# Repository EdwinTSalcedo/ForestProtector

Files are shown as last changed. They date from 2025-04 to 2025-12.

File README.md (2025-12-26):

<h1 align="center">ForestProtector: An IoT Architecture Integrating Machine Vision and Deep Reinforcement Learning for Efficient Wildfire Monitoring</h1> 

This repository contains supplementary material for the paper [*"ForestProtector: An IoT Architecture Integrating Machine Vision and Deep Reinforcement Learning for Efficient Wildfire Monitoring"*](https://ieeexplore.ieee.org/document/10977677) (ICARA 2025). **Authors:** [Kenneth Bonilla-Ormachea](https://www.linkedin.com/in/kenneth-bonilla-ormachea-58b7a9240/), [Horacio Cuizaga](https://www.linkedin.com/in/horacuizr/), [Edwin Salcedo](https://www.linkedin.com/in/edwinsalcedo), [Sebastian Castro](https://www.linkedin.com/in/sebastian-castro-3969641a6), [Sergio Fernandez-Testa](https://www.linkedin.com/in/sergio5919/), and [Misael Mamani](https://www.linkedin.com/in/misaelmq680/).  

[[Project Page]](https://edwinsalcedo.com/publication/forest-protector) 
[[Preprint]](https://arxiv.org/abs/2501.09926)
[[Demo Video]](https://youtu.be/jGAHsTo3gg0)

<p align="center">
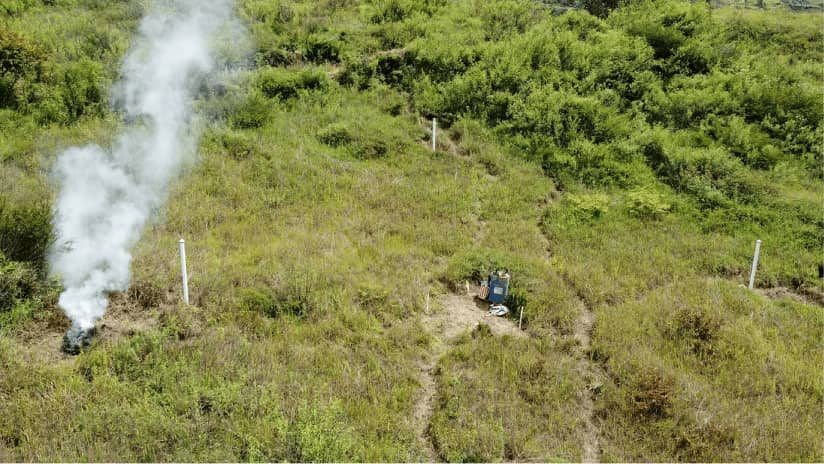
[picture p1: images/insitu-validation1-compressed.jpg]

</p>  

## TL;DR
- **Problem:** Early wildfire detection over large forest areas is critical in wildfire-prone regions. However, existing solutions are often expensive or prone to false positives.
- **Solution:** A low-cost wildfire detection system based on distributed IoT sensor nodes and a central edge gateway with computer vision monitoring a 360° field of view.
- **Key contribution:** A deep reinforcement learning agent dynamically controls the camera orientation based on real-time sensor data (smoke, temperature, humidity) and verifies smoke presence through a 3DCNN-based video recognizer, reducing false positives.

## Contents
[1. Overview](#overview) </br>
* [Motivation](#motivation) </br>
* [IoT architecture](#iotarchitecture) </br>
* [Hardware prototype](#hardwareprototype) </br>

[2. Deep reinforcement learning agent](#drlagent) </br>

[3. Computer vision system](#cvsystem) </br>
* [Datasets](#datasets) </br>
* [Detection metrics](#metrics) </br>
* [Demo](#demo) </br>

[4. Graphical user interface (GUI)](#gui) </br>

[5. Validation](#validation) </br>

[6. Project structure](#projectstructure) </br>

[7. Citation](#citation) </br>
<br>

## 1. Overview

### Motivation

Early detection of forest fires is crucial to minimizing environmental and socioeconomic damage, as longer-burning fires are significantly harder and costlier to extinguish. However, current detection systems using technologies like remote sensing, PTZ cameras, and UAVs are often expensive and require human involvement, limiting their practicality for continuous large-scale monitoring. To address this, we propose a system that uses a low-cost central gateway with computer vision to monitor a 360° field of view for smoke at long distances. A deep reinforcement learning agent enhances surveillance by dynamically adjusting the camera's orientation based on real-time data from distributed IoT sensors measuring smoke, temperature, and humidity.

### IoT architecture
The proposed system architecture consists of two main components: IoT sensor nodes and a central gateway. The sensor nodes, deployed near forests, monitor environmental conditions using various sensors, including those for temperature, humidity, barometric pressure, smoke, and water. The central gateway, based on an NVIDIA Jetson Nano board, collects data from these nodes via the LoRa protocol. The gateway then utilizes a deep reinforcement learning agent to control the gateway camera's perspective, focusing on potential nearby campfires, and employs a computer vision algorithm to verify the presence of smoke in the high-risk region.

<p align="center">
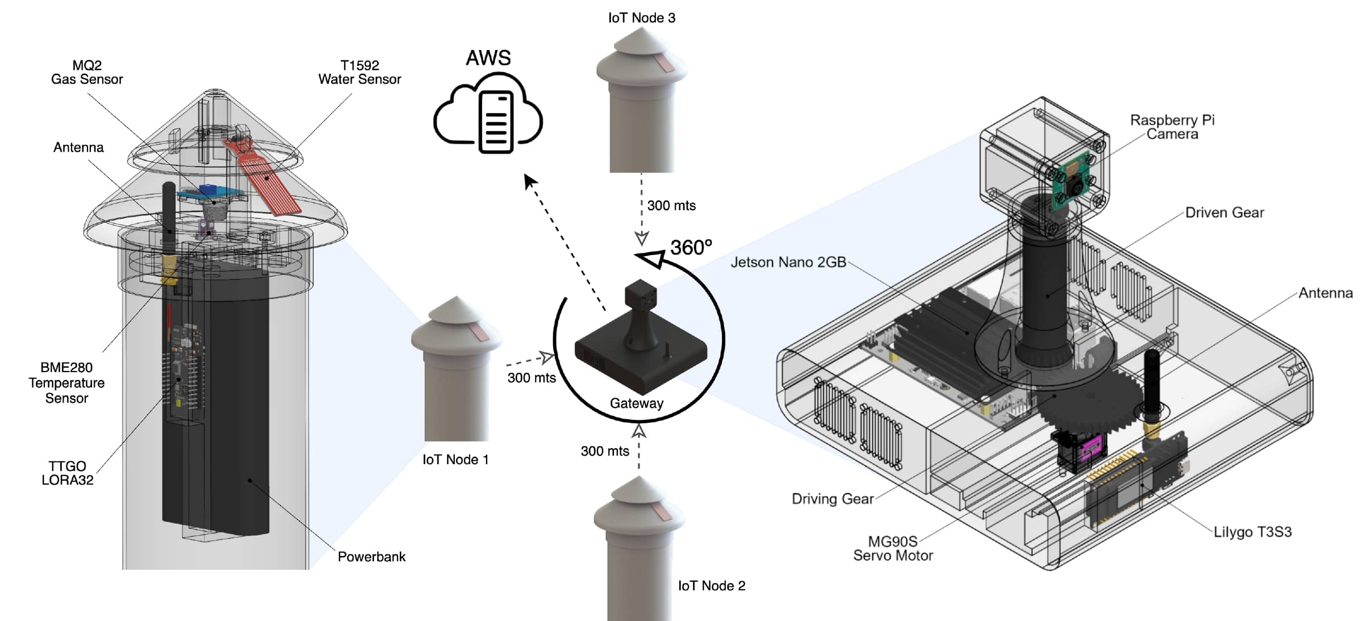
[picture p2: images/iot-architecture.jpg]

</p>

### Hardware prototype

We designed custom enclosures for the IoT nodes and gateway using SolidWorks and 3D-printed them with PETG (Polyethylene Terephthalate Glycol) material. The hardware implementation details for both modules are provided below:

|  <a href="https://github.com/EdwinTSalcedo/ForestProtector/tree/main/iot_node">IoT Node Documentation</a>  |  <a href="https://github.com/EdwinTSalcedo/ForestProtector/tree/main/gateway">Gateway Documentation</a> | 
|---|---|
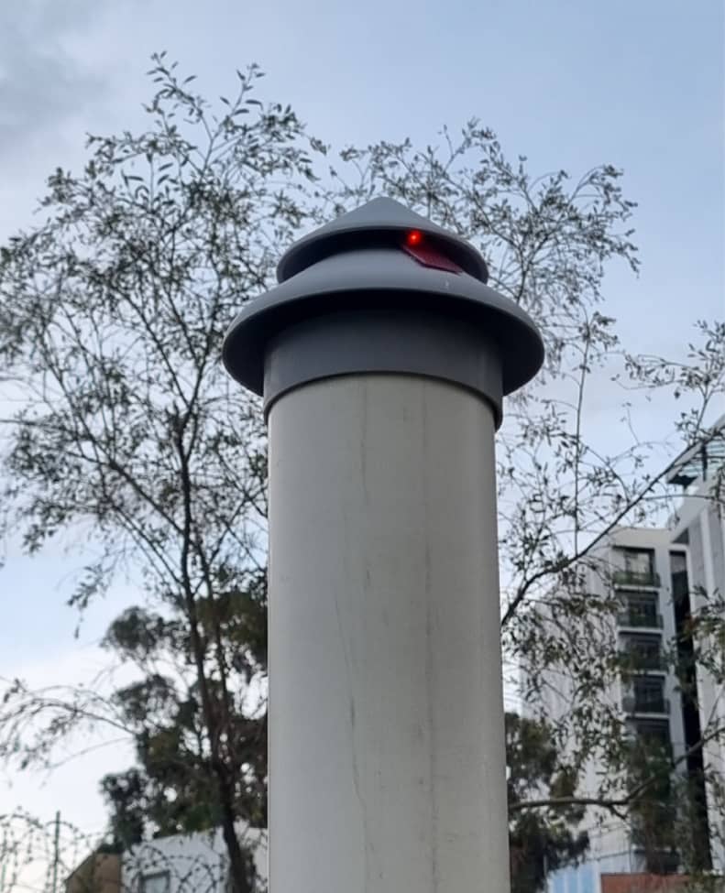
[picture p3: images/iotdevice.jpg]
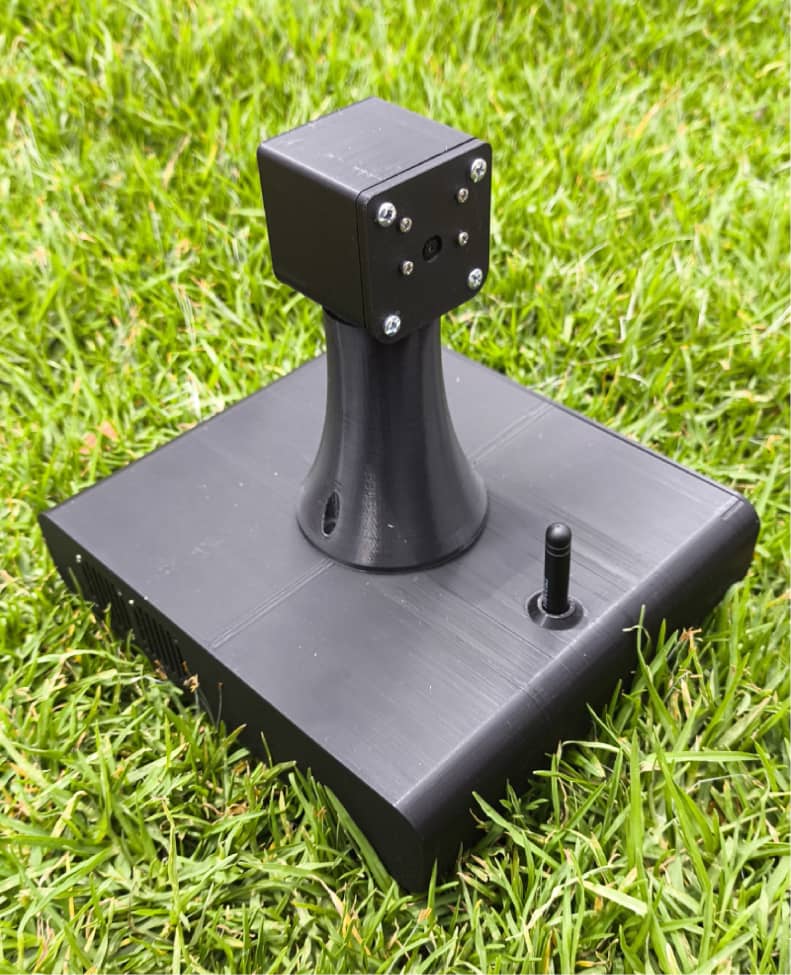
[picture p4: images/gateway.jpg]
| |  |  

## 2. Deep reinforcement learning agent

The DRL agent, embedded within the gateway, learns a policy that selects which camera sector to observe next based on real-time IoT sensor signals. It uses a nine-value state vector (temperature, humidity, and smoke levels for three sectors) and outputs a ranked preference, allowing the gateway camera to focus on the region with the highest estimated risk.

### Getting started

This quickstart runs a **reproducible, minimal demo** of the agent. The full implementation is available in `drl/notebooks`.

#### 1. Create and activate the Conda environment
```bash
conda env create -f environment.yml
conda activate forestprotector
```

#### 2. Run the DRL policy demo (interactive)
This script loads the trained model from `drl/model/camera_ctrl.h5` and prompts you for sensor readings.

```bash
(forestprotector) python drl/scripts/DRL.py
```

## 3. Computer vision system

The 24/7 fire monitoring system comprises two modalities. During the day, it prioritizes smoke detection over fire detection, as smoke is a more visible indicator of wildfires from long distances. To achieve this, we implemented a 3D-CNN trained on a combination of real and synthetic videos of smoke plumes and wildfires captured at various distances. At night, the system prioritizes the detection of bright regions using techniques such as color thresholding, background subtraction, and others to identify fires. The entire computer vision pipeline is depicted below: 

<p align="center">
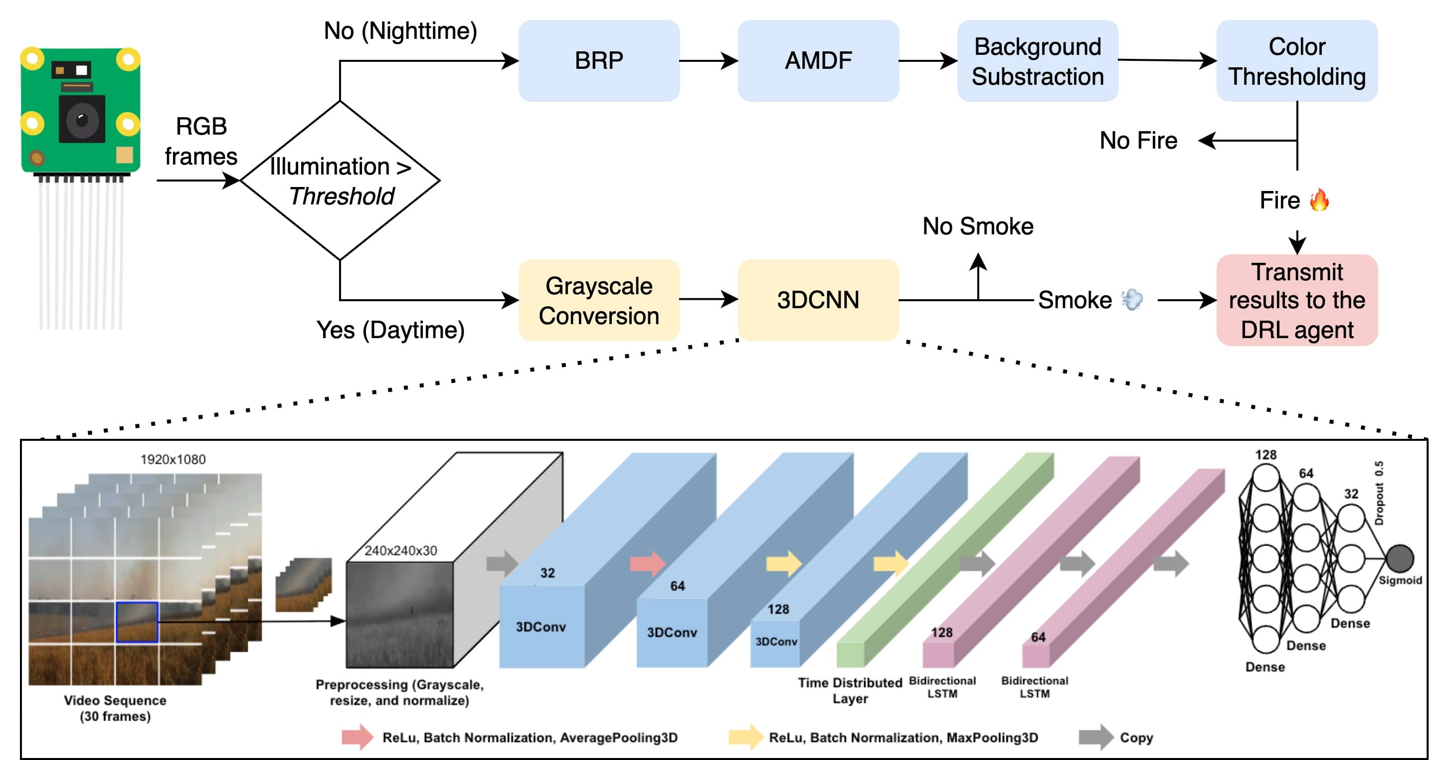
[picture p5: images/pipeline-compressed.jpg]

</p>

### Datasets

The computer vision system required the collection of two datasets ([available here](https://drive.google.com/drive/folders/16Fxw01cgJtipfyKjr5r_unSuSZd61Ahs?usp=sharing)): 

- **Nighttime Fire Detection (NFD) Dataset**  &rarr; Consists of 100 forest videos captured during nighttime, with and without fire (50 per category). 
- **Smoke Detection (SD) Dataset**  &rarr; To train the 3DCNN, we collected 1,398 forest videos using web scraping, generative AI, and video editing tools. The following table summarises this dataset. Note that we later augmented this dataset to obtain 2,000 videos per category.

| Class | Scrapped Videos | AI-generated Videos | Videos Generated with After Effects | Total | Aug.  |
|---|---|---|---|---|---|
| With Smoke | 108 | 443 | 184 | 735 | 2,000  |
| Without Smoke  | 663 | 0 | 0 | 663 | 2,000  |
| **Total** | **771** | **443** | **184** | **1,398** | **4,000** |

### Detection metrics

Our approach achieved accuracies of 92.5% and 88% for daytime and nighttime fire detection, respectively. See the following confusion matrices obtained with the NFD and SD datasets for further analysis.

|  Daytime smoke detection | Nighttime fire detection | 
|---|---|
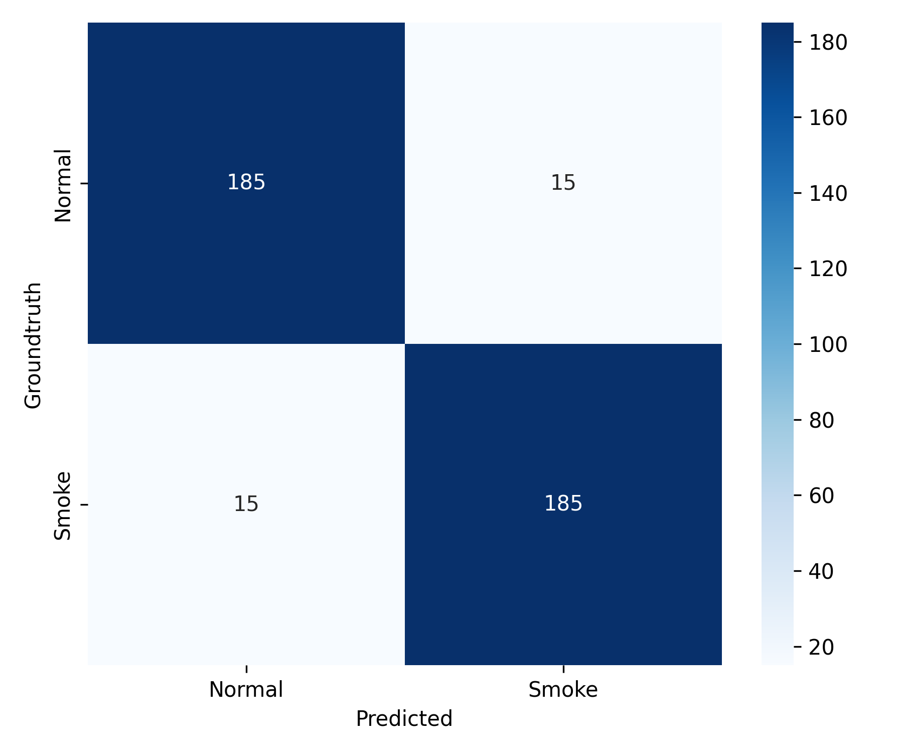
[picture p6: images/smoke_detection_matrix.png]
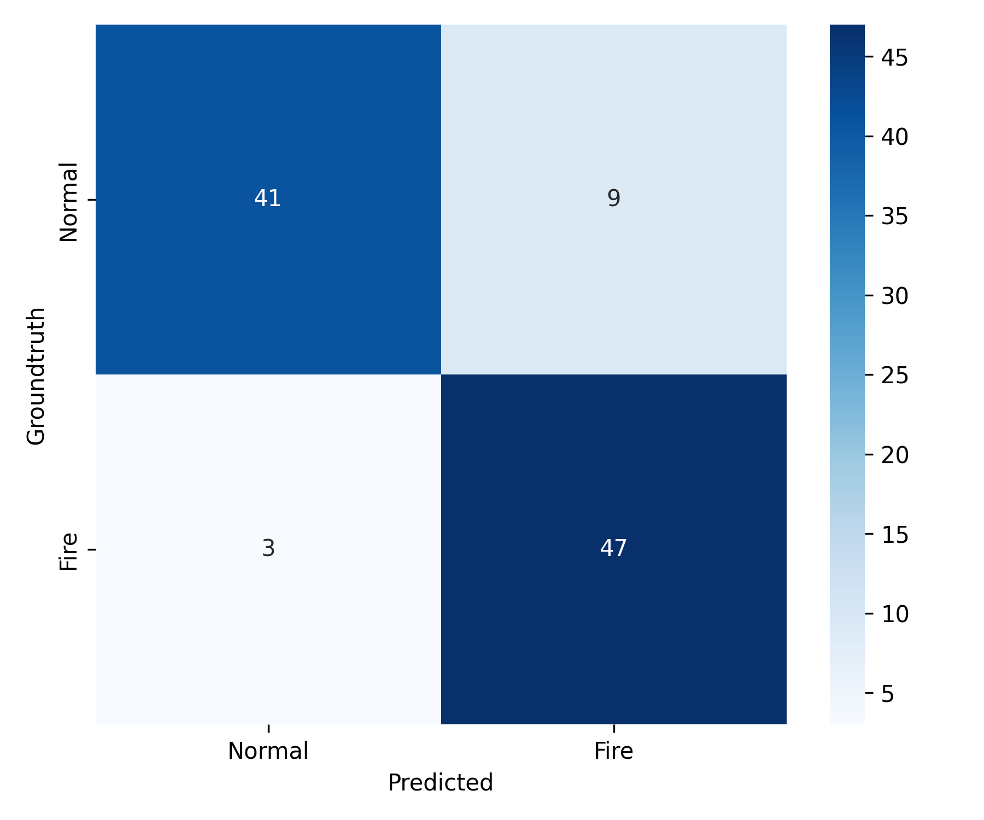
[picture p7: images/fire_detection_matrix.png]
| |  |  

### Demo

Once inside the `forestprotector` environment, execute the following command to run the demo:

```bash
(forestprotector) python cv/run_demo.py
```

This script runs a **reproducible, minimal demo** of the daytime smoke detector and nighttime fire detector using the sample videos in `cv/samples`.  
The demo automatically distinguishes between day and night based on mean illumination and routes each video to the appropriate detector.  
It outputs smoke/no-smoke decisions for daytime videos and fire/no-fire decisions for nighttime videos. The model `cv/daytime/model/smoke.keras` is used for smoke inference.

## 4. Graphical User Interface (GUI)

The GUI provides a real-time dashboard for incoming IoT data, alert notifications, and system status. It consists of a Node.js backend (API + WebSockets + WhatsApp alerts) and a React/Vite frontend for live charts and filters. For setup and run instructions, see [webapp/README.md](webapp/README.md).

<p align="center">
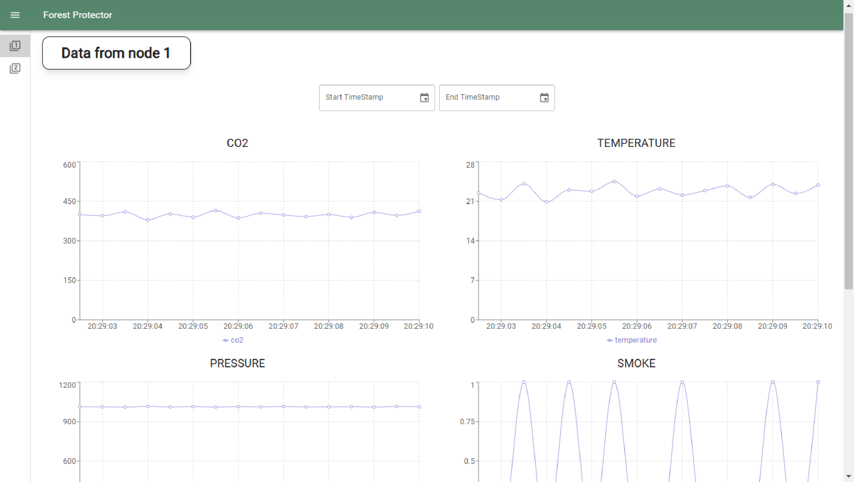
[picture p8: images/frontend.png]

</p>

## 5. Validation

Additional field tests were conducted in the rural area of Sorata, La Paz, Bolivia ([Google Maps Location](https://maps.google.com/?q=-15.730436,-68.680162)), to further validate the system under real-world conditions. These tests corroborated the system’s ability to prioritize high-risk areas, verify wildfire indicators, and issue timely alerts in outdoor environments. A final demonstration video of the deployed system is available at:  
https://youtu.be/jGAHsTo3gg0

## 6. Project structure

```text
.
├── cv/                  # Day/night computer vision scripts and notebooks.
│   ├── daytime/         # Daytime smoke detection notebooks and scripts.
│   ├── nighttime/       # Nighttime fire detection scripts and data.
│   └── samples/         # Sample videos used by the unified demo.
├── drl/                 # Deep reinforcement learning agent code and models.
│   ├── model/           # Trained DRL policy.
│   ├── scripts/         # DRL inference demo script.
│   └── notebooks/       # Training and analysis notebooks.
├── gateway/             # Gateway firmware and mechanical design files.
│   ├── 3d_printing_files/ # Printable STL/3MF parts.
│   └── cad_files/       # CAD source files.
├── iot_node/            # IoT node firmware and enclosure CAD files.
│   ├── 3d_printing_files/ # Printable STL/3MF parts.
│   └── cad_files/       # CAD source files.
├── webapp/              # Web dashboard, backend API, and microcontroller code.
│   ├── backend/         # Node.js API, WebSockets, and WhatsApp alerts.
│   ├── frontend/        # React/Vite dashboard.
│   └── microcontrollers/ # Jetson/NodeMCU/Pi Pico integration code.
├── images/              # Figures used in documentation.
├── deployment/          # On-device deployment utilities (Jetson).
├── README.md            # Main project documentation.
├── environment.yml      # Conda environment for demos.
└── LICENSE.md           # License information.
```

## 7. Citation

If you find *ForestProtector* useful in your project, please consider citing the following paper:

```
@INPROCEEDINGS{bonilla2025,
  author={Bonilla-Ormachea, Kenneth and Cuizaga, Horacio and Salcedo, Edwin and Castro, Sebastian and Fernandez-Testa, Sergio and Mamani, Misael},
  booktitle={2025 11th International Conference on Automation, Robotics, and Applications (ICARA)}, 
  title={ForestProtector: An IoT Architecture Integrating Machine Vision and Deep Reinforcement Learning for Efficient Wildfire Monitoring}, 
  year={2025},
  volume={},
  number={},
  pages={70-75},
  doi={10.1109/ICARA64554.2025.10977677}}
```

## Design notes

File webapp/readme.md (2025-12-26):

# ForestProtector Web App

## Description

This web app provides real-time visualization, alerting, and data ingestion for the ForestProtector system. It is split into three parts:

- backend: receives IoT sensor data, serves APIs/WebSockets, and sends WhatsApp alerts.
- frontend: displays the live dashboard and alerts.
- microcontrollers:
  - Jetson: runs the edge vision logic and reports detections to the backend.
  - NodeMCU: bridges sensor data to the Jetson.
  - Pi Pico: collects sensor data and sends it over LoRa to the NodeMCU.

## Folder Structure

```bash
.
├── backend # Node.js API + WebSockets + WhatsApp alerts.
├── frontend # React/Vite dashboard.
├── microcontrollers
│   ├── jetson # Python services for Jetson.
│   ├── nodeMCU # Arduino firmware for NodeMCU.
│   └── piPico # MicroPython firmware for Raspberry Pi Pico.
└── readme.md
```

## Backend

### Requirements
- Node.js 18+
- MongoDB (local or hosted)
- pnpm (recommended)

### Setup
```bash
cd webapp/backend
cp .env.example .env
```

Update `.env` with your MongoDB connection and runtime mode:
```
MONGO_URI=...
ENVIRONMENT=development
PORT=3000
```

### Run
```bash
pnpm install
pnpm dev
```

The server starts on `http://localhost:3000` and exposes:
- REST endpoints under `/node/:node` for IoT data ingestion.
- WebSocket updates for live dashboards.
- Swagger docs at `/api-docs`.

## Frontend

### Run
```bash
cd webapp/frontend
pnpm install
pnpm dev
```

The UI starts on the Vite dev server and connects to the backend over HTTP/WebSockets.

## Microcontrollers

Reference implementations are under `webapp/microcontrollers`:
- Jetson Python code: `webapp/microcontrollers/jetson`
- NodeMCU firmware: `webapp/microcontrollers/nodeMCU`
- Pi Pico firmware: `webapp/microcontrollers/piPico`

Each folder contains platform-specific code and requirements.

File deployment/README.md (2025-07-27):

# Camera Control & Smoke Detection System on Jetson Nano

## Overview

This section of the project integrates two deep learning models on a Jetson Nano to enable intelligent wildfire detection and response:

- **Camera Control Model (DQN)**: A reinforcement learning agent that decides where to point a camera based on sensor readings (temperature, humidity, smoke).
- **Smoke Detection Model (CNN/3D CNN)**: A vision model that analyzes live video to determine the presence of smoke.

---

## Project Components

### 🔧 Scripts

- `DRL.py`  
  → Predicts optimal camera direction manually via terminal input using the DQN model.

- `jetson.py`  
  → Main integrated script to run on Jetson Nano. Reads sensor data via serial, controls a servo motor, and triggers smoke detection from a connected camera.

- `smoke_vision_inference.py`  
  → Predicts smoke presence from a video file using the 3D CNN model.

### 📁 Models

- `dqn_model.h5` or `camera_ctrl.h5`  
  → Trained DQN model for sector prediction.

- `vision_model.h5` or `smoke.keras`  
  → Trained smoke detection model.

---

## Setup & Execution

### 1. Install Dependencies
Create a virtual environment (optional) and install dependencies:

```bash
pip install -r requirements.txt
```

### 2. Run on Jetson Nano
Ensure models are in the working directory, then run:

```bash
python jetson.py
```

### 3. Manual Testing
Use `DRL.py` or `smoke_vision_inference.py` to test each model individually.

---

## Notes

- Ensure correct serial port access for reading sensor data (`/dev/ttyUSB0`).
- For smoke detection, the camera must be accessible via OpenCV.
- Models must be trained separately and placed alongside the scripts.

---

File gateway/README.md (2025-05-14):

<h1 align="center">LoRa Gateway</h1>

<p align="center">
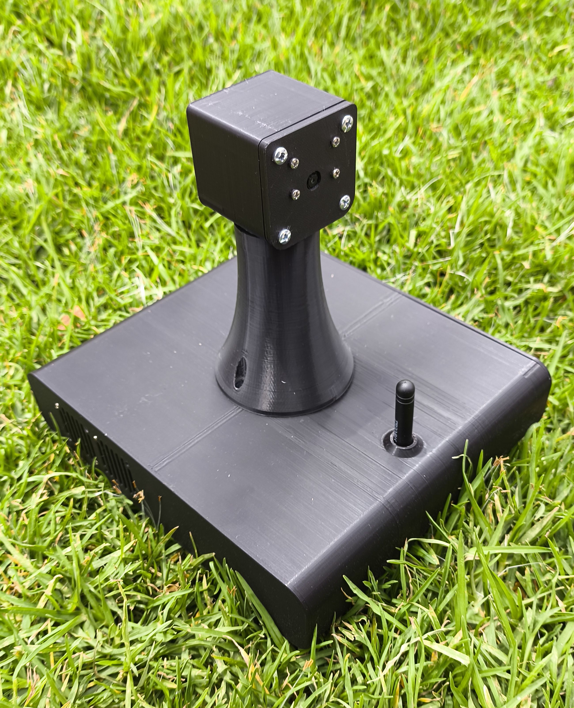
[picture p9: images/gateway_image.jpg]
LoRa Gateway
  
</p>

This directory contains the firmware, hardware wiring, and configuration details for the central gateway of the ForestProtector wildfire monitoring system. The gateway receives data from IoT sensor nodes via LoRa and performs processing based on a reinforcement learning algorithm. This algorithm enables the system to dynamically determine which area the thermal surveillance camera should focus on, optimizing zone monitoring effectiveness.

The intelligent processing is handled by a **Jetson Nano**, which receives data through a **LilyGo T3S3** microcontroller equipped with LoRa connectivity. This setup ensures efficient, low-power communication while maintaining a modular and scalable architecture. The Jetson analyzes the input data and computes an optimal motion policy, generating commands that drive a camera positioning system to point toward the selected critical zone.

This system is designed to operate autonomously in forest environments, prioritizing high-risk areas based on the real-time sensor data collected by remote nodes.

## Contents  
[1. Components](#components) </br>
[2. Schematic diagram](#wiring) </br>
[3. Files included](#files) </br>
[4. Physical design and assembly](#design) </br>
[5. Library setup](#libraries) </br>
[6. Firmware behavior](#firmware) </br>
[7. Field deployment considerations](#considerations) </br>
<br>

## 1. Components

- **LilyGo T3S3 V1.1** – ESP32-S3 microcontroller with integrated SX1262 LoRa transceiver  
- **Jetson Nano** – Embedded computer with ARM Cortex-A57 CPU and Maxwell GPU, used for reinforcement learning-based decision making  
- **Pi Camera Module (Rev 1.3)** – Camera connected to the Jetson Nano via CSI interface for thermal or visual monitoring  
- **SG90 Servo** – Servo motor for pan or tilt control of the camera  
- **LoRa Antenna** – External 868 MHz/915 MHz antenna for long-range communication  
- **3D Printed Enclosure** – Enclosure designed in PETG for weather resistance (UV and moisture protection)  
- **Power Supply** – Power source compatible with Jetson Nano (e.g., 5V–4A via USB-C or 5.5 mm barrel connector)  
- **2x 5V Fans** – Used for active cooling of the Jetson Nano and airflow within the enclosure  
- **20x32x7 mm Bearing** – Provides smooth rotation support for the camera platform

## 2. Schematic diagram

<p align="center">
  Gateway wiring
</p>
*(to be completed)*

## 3. Files included

- [`gateway_code.ino`](gateway_code.ino): Arduino firmware for the LilyGo T3S3 microcontroller. It receives LoRa packets, parses the data sent by the IoT sensor nodes, and forwards it to the Jetson Nano via serial communication. It also receives commands from the Jetson to control the servo responsible for camera orientation.

- `python/` *(to be completed)*: Folder intended for the scripts that run on the Jetson Nano. These include the reinforcement learning algorithm, Q-table management, camera control, and communication with the microcontroller.

- `cad_files/`: Editable 3D design files created in SolidWorks.
  - The main part file for customizing the gateway enclosure is [`gateway_parts.SLDPRT`](cad_files/gateway_parts.SLDPRT).
  - [`gateway_with_electronics.SLDASM`](cad_files/gateway_with_electronics.SLDASM) contains the full assembly with electronic components integrated in their intended positions.

- `3d_printing_files/`: STL files ready for 3D printing.  
  - This folder also includes [`gateway_all_parts.3mf`](3d_printing_files/gateway_all_parts.3mf), a pre-arranged layout with all parts correctly positioned and oriented for slicing and export.

## 4. Physical Design and Assembly

The physical design of the gateway is essential to ensure proper operation under various environmental conditions. We recommend housing the components in a weatherproof enclosure, such as an IP65-rated box, which will protect the electronics from dust, water, and other environmental factors. For this project, alternatively, the system can be placed under a roof or surface that shields it from direct sunlight and rain.

**Recommended 3D printing settings:**
- Material: PETG (preferred over PLA due to its superior outdoor durability)
- Layer height: 0.2 mm
- Infill: 20–30%
- Orientation: All STL files in the [`3d_printing_files`](3d_printing_files) folder are pre-oriented for printing. Some parts may require supports, but all were designed to minimize or eliminate their use.

**Assembly steps:**

1. Print all parts available in the [`3d_printing_files`](3d_printing_files) folder.
2. Connect all components to their respective cables: Jetson Nano to its power supply, T3S3 to its power cable, and the camera to the CSI cable.
3. Insert the [`servo_gear_camera_drive.stl`](3d_printing_files/servo_gear_camera_drive.stl) part onto the already mounted SG90 servo shaft, securing it with the screws provided with the motor.
4. Mount the two 5V fans to the bottom of the [`gateway_enclosure.stl`](3d_printing_files/gateway_enclosure.stl) part and secure them using appropriate screws.
5. Place the T3S3 board, Jetson Nano, and SG90 servo motor in their designated slots inside [`gateway_enclosure.stl`](3d_printing_files/gateway_enclosure.stl). Secure the Jetson and the motor using one screw each.
6. To secure the T3S3, insert the LoRa antenna through the top opening of [`gateway_enclosure.stl`](3d_printing_files/gateway_enclosure.stl), and fix it using the matching nuts and adjustment pieces.
7. For the camera assembly: first, attach the camera module to [`camera_module_cover.stl`](3d_printing_files/camera_module_cover.stl) using the appropriate screws. Insert a bearing into [`camera_gear_connector.stl`](3d_printing_files/camera_gear_connector.stl), then mount [`camera_cable_pillar.stl`](3d_printing_files/camera_cable_pillar.stl) into the bearing. Connect all parts with screws. The bearing allows smooth movement of the assembly.
8. Next, join [`camera_module_enclosure.stl`](3d_printing_files/camera_module_enclosure.stl) to the previously assembled camera module using the same screws. Route the camera cable through the provided slot and secure [`camera_module_enclosure.stl`](3d_printing_files/camera_module_enclosure.stl) to [`camera_module_cover.stl`](3d_printing_files/camera_module_cover.stl), completing the pan-tilt structure.
9. Insert the fully assembled camera module into [`gateway_enclosure.stl`](3d_printing_files/gateway_enclosure.stl), ensuring that the gears mesh properly. Secure the module with two screws; the height will auto-align.
10. **Additional recommendation:** Ensure that the servo motor is set to its initial position before meshing the drive gear and camera gear. This step ensures proper alignment of movement and helps protect the CSI cable from torsion or damage.
11. Finally, close the enclosure by screwing on the [`gateway_enclosure_cover.stl`](3d_printing_files/gateway_enclosure_cover.stl) part, using it as a lid. Make sure to leave the Jetson Nano's power cable routed through the dedicated notch or opening to exit the enclosure safely.

**Assembly reference:**

<p align="center">
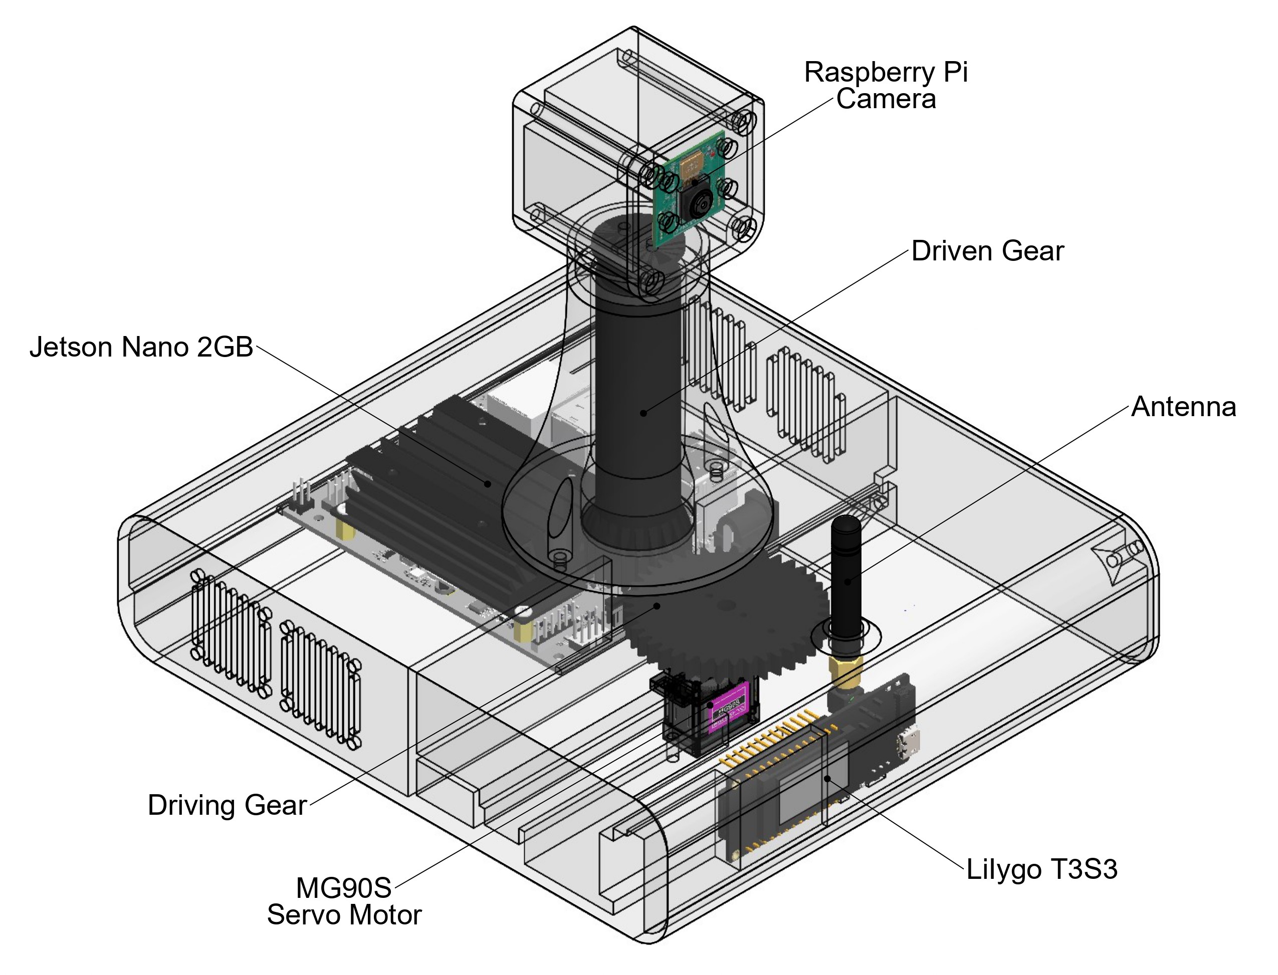
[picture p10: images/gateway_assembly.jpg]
  
</p>

## 5. Library Setup

To compile the gateway firmware and run the scripts, you need the following:

### Arduino IDE (for LilyGo T3S3)
- **Board support**: Install "ESP32 by Espressif Systems" by adding the following URL in *Preferences*:  
  `https://raw.githubusercontent.com/espressif/arduino-esp32/gh-pages/package_esp32_index.json`

- **Required libraries**:
  - `LoRa` by Sandeep Mistry

- **Development environment configuration**:  
  When using the **LilyGo T3S3** board, you must manually adjust the board settings in the Arduino IDE to ensure proper operation. Use the following recommended configuration:

| Option | Value |
|---|---|
| Board | ESP32S3 Dev Module |
| Port | Your board’s port |
| USB CDC On Boot | Enable |
| CPU Frequency | 240MHz (WiFi) |
| Core Debug Level | None |
| USB DFU On Boot | Disable |
| Erase All Flash Before Upload | Disable |
| Events Run On | Core1 |
| Flash Mode | QIO 80MHz |
| Flash Size | 4MB (32Mb) |
| Arduino Runs On | Core1 |
| USB Firmware MSC On Boot | Disable |
| Partition Scheme | Huge APP (3MB No OTA / 1MB SPIFFS) |
| PSRAM | QSPI PSRAM |
| Upload Mode | UART0 / Hardware CDC |
| Upload Speed | 921600 |
| USB Mode | CDC and JTAG |
| Programmer | Esptool |

Also, make sure to **uncomment the appropriate board in the `utilities.h` file** of your sketch according to the model you're using. Otherwise, compilation will fail.

> For more details on configuring this board, refer to the official LilyGo documentation:  
> [LilyGo LoRa Series GitHub Repository](https://github.com/Xinyuan-LilyGO/LilyGo-LoRa-Series)

### (for Jeston Nano)
*(to be completed)*

## 6. Firmware Behavior

The gateway system consists of two main components:

### LilyGo T3S3 (LoRa Gateway)
This microcontroller acts as the central receiver for environmental monitoring data sent from remote sensor nodes. Its operation can be summarized as follows:

1. **LoRa Module Initialization**  
   In the `setup()`, the SPI pins for the LoRa module are manually defined, and the transceiver is initialized at 915 MHz. If the initialization fails, the system halts.

2. **Data Reception**  
   Inside the `loop()`, the device continuously listens for incoming LoRa packets using `LoRa.parsePacket()`. When a packet is received:
   - The full message is read into a `String`.
   - The `processReceivedData()` function is called to interpret its contents.

3. **Received Data Processing**  
   The expected message format is:  
   `<NODE_ID>:<mq2>,<rain>,<temperature>,<humidity>`  
   Example: `2:1234,0,55.3,48.1`  
   Where:
   - `NODE_ID` identifies the transmitting node (1, 2, or 3).
   - `mq2` is the raw smoke sensor value (mapped to a 0–100 scale).
   - `rain` is the raw rain sensor value.
   - `temperature` and `humidity` are in °C and %RH respectively.

   The function:
   - Associates the data to the corresponding node (`node1`, `node2`, or `node3`).
   - Applies binary thresholds: temperature > 50°C and humidity > 45% are set to 1; otherwise, 0.
   - Logs the last update time for the node.

4. **Periodic Display**  
   Every 5 seconds, the `displayNodeData()` function prints the latest data for all nodes to the Serial Monitor. If a node has not updated its data in more than 10 seconds, it reports "No recent data received."

### Jetson Nano (AI Agent and Decision Unit)
*(to be completed)*

> This architecture enables the gateway to function as an intelligent hub, receiving, interpreting, and routing data to the AI-based decision unit.

## 7. Field Deployment Considerations

When deploying the gateway in real-world scenarios, take the following aspects into account:

### Antenna Placement
- Position the LoRa antenna in a high, unobstructed location with line-of-sight to the sensor nodes.
- Avoid major obstacles (walls, dense trees, metallic structures) that may degrade the signal.
- If needed, use external high-gain antennas to increase communication range.

### Power Supply
- Use a stable power source, ideally a **USB-C power bank** with reliable output.
- Alternatively, consider a **solar panel + rechargeable battery** solution for long-term remote deployments.

### Environmental Protection
- The gateway must be housed in a weather-resistant enclosure:
  - Waterproof (IP65 or higher).
  - UV-resistant if exposed to direct sunlight.
- Properly seal all joints and leave a secure path for the power cable without exposing the system to water ingress.

### Cooling
- Although the Jetson Nano includes fans, make sure they are functioning properly, especially in warm environments or during extended high-load operation.

### Maintenance
- Perform regular checks on:
  - Servo alignment and movement.
  - Cable and connector integrity.
  - Camera focus and positioning.
- Ensure that communication with sensor nodes remains stable over time.

> This modular gateway design allows future expansion, such as multiple LoRa channels, cloud service integration, or additional modules for intelligent decision-making and alerting.

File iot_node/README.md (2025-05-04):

<h1 align="center">IoT Sensor Node</h1>

<p align="center">
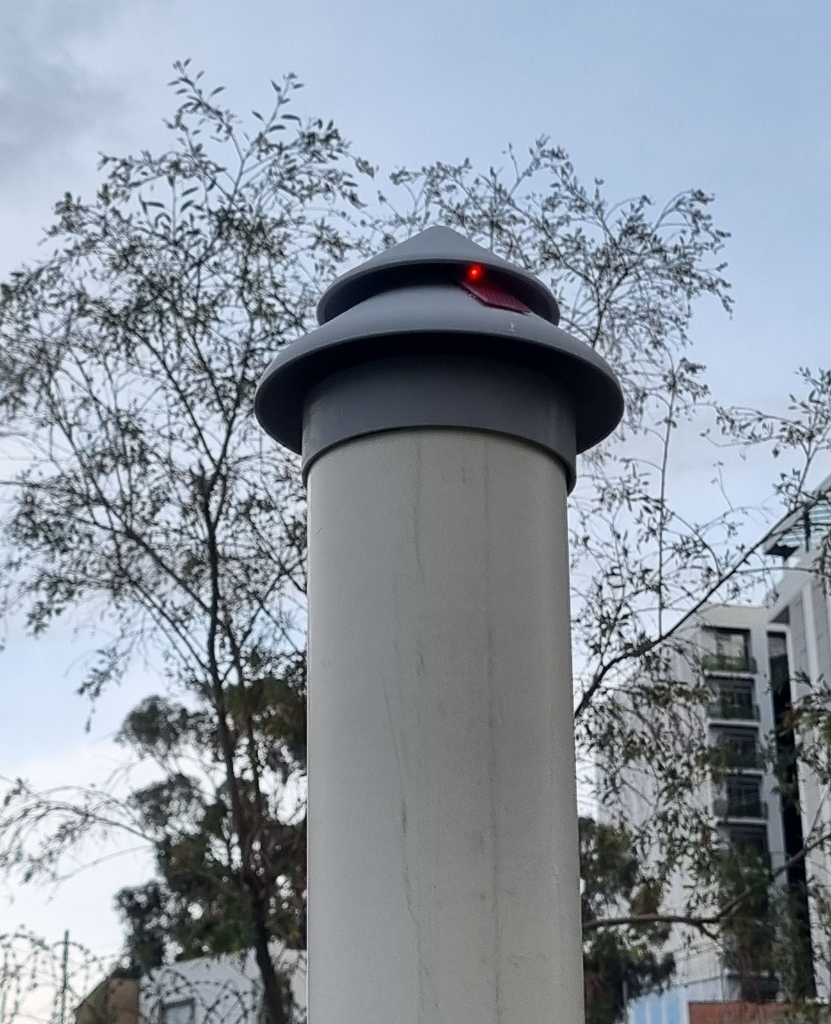
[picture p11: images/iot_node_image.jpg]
IoT Sensor Node
  
</p>

This directory contains the firmware, hardware design, and assembly documentation for the IoT sensor nodes used in the ForestProtector wildfire monitoring system. These nodes collect environmental data (gas, temperature, humidity, rain) and send it wirelessly to the central gateway via LoRa communication.

## Contents  
[1. Components](#components) </br>
[2. Schematic diagram](#wiring) </br>
[3. Files included](#files) </br>
[4. Physical design and assembly](#design) </br>
[5. Library setup](#libraries) </br>
[6. Firmware behavior](#firmware) </br>
[7. Field deployment considerations](#considerations) </br>
<br>

## 1. Components

- **TTGO LoRa32 V1.0** – ESP32 microcontroller with built-in SX1276 LoRa module  
- **BME280** – environmental sensor for temperature, humidity, and pressure (I2C)  
- **MQ2** – gas and smoke sensor (analog output)  
- **T1592** – rain sensor (analog output)  
- **3D printed enclosure** – printed in PETG for outdoor resistance  
- **5V power source** – LiPo battery or USB power bank

## 2. Schematic diagram

<p align="center">
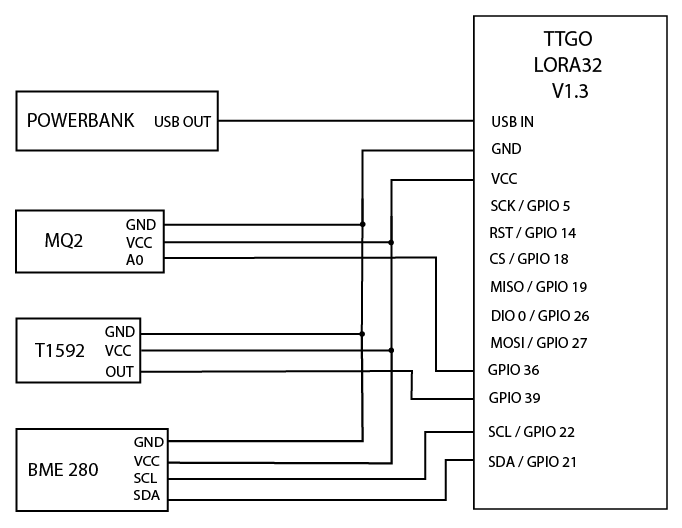
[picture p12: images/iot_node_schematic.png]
  
</p>

The diagram above illustrates the physical wiring between the TTGO LoRa32 board and the environmental sensors. Note that the LoRa transceiver is integrated into the TTGO board, and its SPI pins must be explicitly set in the firmware. The BME280 communicates over I2C, while the MQ2 and T1592 sensors use analog outputs connected to GPIO36 and GPIO39, respectively. Ensure that sensors requiring 3.3V or 5V are connected accordingly to avoid damage.

## 3. Files included

- [`iot_node_code.ino`](iot_node_code.ino): Arduino code for the sensor node. It reads data from the sensors and sends it to the T3S3 board at the gateway via LoRa using a structured string array. The code evaluates thresholds for temperature, humidity, and gas levels, and sends only key status indicators. To deploy this firmware, upload it to the TTGO LoRa32 board using the Arduino IDE.

- `cad_files/`: Editable 3D design files created in SolidWorks.  
  - The main part file for customizing the node's structure is [`design1.SLDPRT`](cad_files/design1.SLDPRT).  
  - [`new_roof.SLDPRT`](cad_files/new_roof.SLDPRT) contains an alternative version of the rain shield.  
  - [`iot_node.SLDASM`](cad_files/iot_node.SLDASM) assembles all parts and includes virtual models of the electronic components in their correct positions.

- `3d_printing_files/`: STL files ready for 3D printing.  
  - This folder also includes [`iot_node_all_parts.3mf`](3d_printing_files/iot_node_all_parts.3mf), a pre-arranged printing layout with all parts positioned and oriented for slicing and export.

## 4. Physical design and assembly

The node enclosure was designed in SolidWorks and optimized for 3D printing in PETG, which provides enhanced resistance to weather conditions such as UV exposure and humidity. Its geometry allows it to be easily mounted on a standard 4-inch PVC pipe, making it ideal for elevated outdoor deployment in forest environments.

**Recommended 3D printing settings:**
- Material: PETG (preferred over PLA for outdoor durability)
- Layer height: 0.2 mm
- Infill: 20–30%
- Orientation: All STL files in the [`3d_printing_files`](3d_printing_files) folder are pre-oriented for printing. Some parts may require supports, but all were designed to minimize or eliminate their use.

> The part [`iot_node_lower_canopy.stl`](3d_printing_files/iot_node_lower_canopy.stl) contains internal cavities in its leg-like extensions designed to hold M3 nuts. To take advantage of this, a pause should be programmed during the print using your slicer software (e.g., Cura or PrusaSlicer). This feature allows for stronger and more secure assembly.

**Assembly steps:**

1. Print all parts available in the [`3d_printing_files`](3d_printing_files) folder.
2. Connect the **TTGO LoRa32** board to its power cable.
3. Insert the board into the correct slot of the [`iot_node_power_and_boards_holder.stl`](3d_printing_files/iot_node_power_and_boards_holder.stl) part. The second slot is reserved for a Raspberry Pi Pico-R3, considered for future extensions.
4. Place the power bank in the center of the same holder piece, with its USB ports facing downward for easier access.
5. Slide the board holder into the base part [`iot_node_sensor_base.stl`](3d_printing_files/iot_node_sensor_base.stl) and secure them using four 8mm M3 screws.
6. Mount the **BME280** sensor on top of the sensor base, facing upward. Route its wires through the dedicated holes to reach the inner compartment where the microcontroller is located.
7. Attach the LoRa antenna to `iot_node_sensor_base.stl` using its own screws and nuts. The antenna should point vertically upward.
8. Place the **MQ2** sensor (with wires already connected) below and inside the [`iot_node_lower_canopy.stl`](3d_printing_files/iot_node_lower_canopy.stl) part. Run the wires through the side slot designed into one of its vertical columns.
9. Repeat the process with the **T1592 rain sensor**, routing its wires through the same slot.
10. Place the [`iot_node_upper_canopy.stl`](3d_printing_files/iot_node_upper_canopy.stl) over the lower canopy to protect the rain sensor. Secure it with zip ties.
11. Once all sensors are in place, join the following parts using two M3 screws (minimum 30 mm in length):
    - First, secure `iot_node_sensor_base.stl` to `iot_node_main_body.stl` (as if the latter were its lid). At this point, the BME280 sensor and the antenna should protrude through their respective openings.
    - Then pass the same screws through `iot_node_lower_canopy.stl`, locking the full structure together.
12. Before final assembly, make sure that all cables are long enough to reach from the sensors to the board and that they pass properly through the designated cable channels.
13. To attach the device to the PVC pipe, notches must be cut into the pipe. These details can be found in the assembly file [`iot_node.SLDASM`](cad_files/iot_node.SLDASM). Once the pipe is prepared, the enclosure can be twisted onto it as if it were threaded.
14. (Optional) Apply silicone or waterproof sealant around exterior joints to improve resistance to rain or moisture.

**Assembly reference:**

<p align="center">
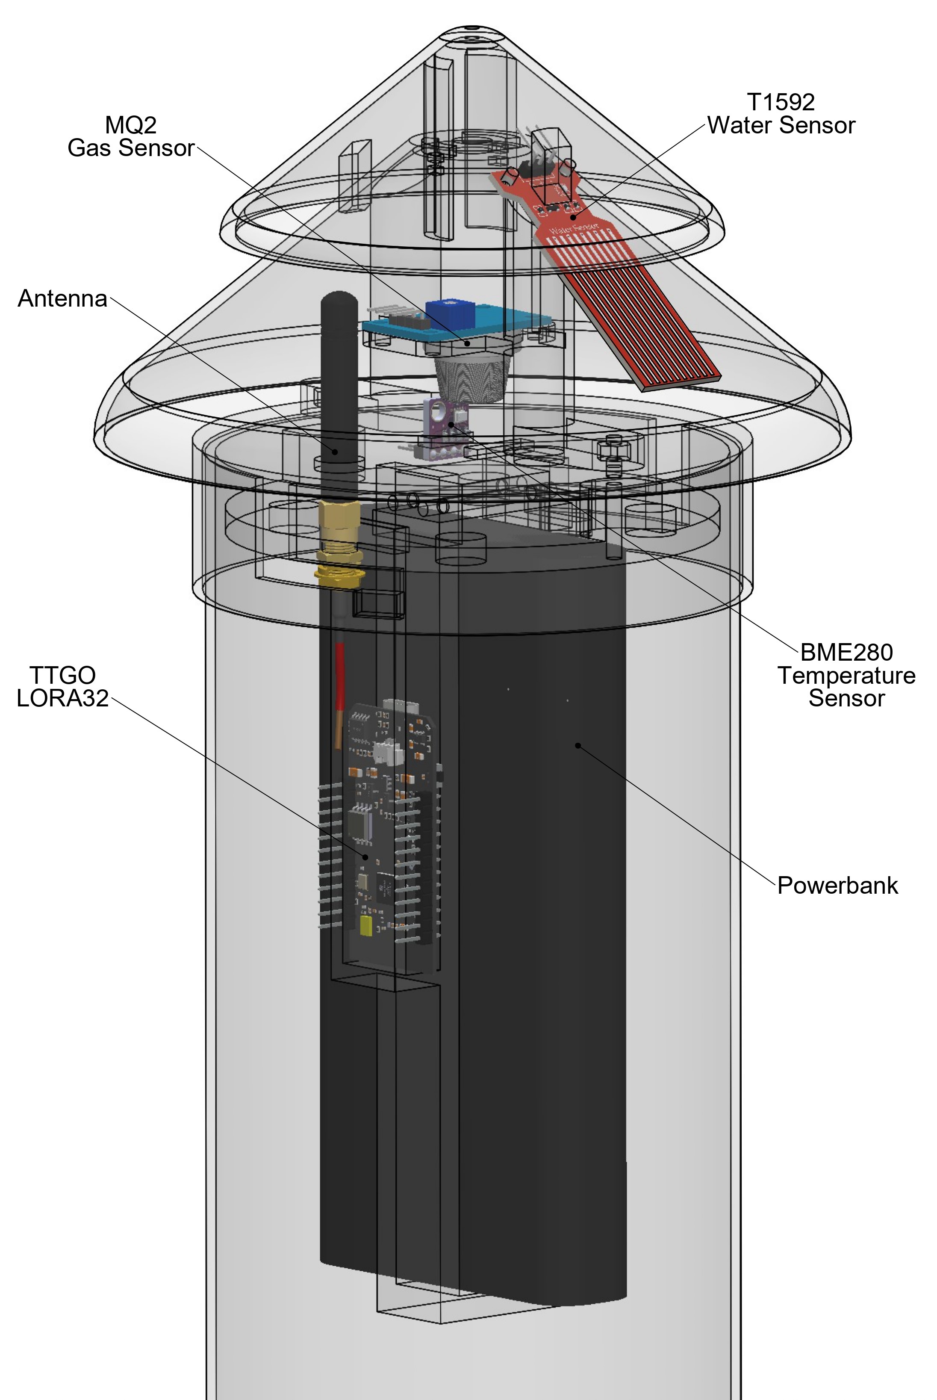
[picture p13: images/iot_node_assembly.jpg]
  
</p>

## 5. Library setup

To compile and upload the code to the TTGO LoRa32 board, use the **Arduino IDE** (version 1.8.19 or newer is recommended, or the latest Arduino 2.x release).

First, install the **ESP32 board support**:

- Go to: `File > Preferences` and add this URL to *Additional Board URLs*:
  ```
  https://raw.githubusercontent.com/espressif/arduino-esp32/gh-pages/package_esp32_index.json
  ```
- Then go to: `Tools > Board > Boards Manager`, search for **ESP32**, and install the package by *Espressif Systems*.

### Required libraries

Install these libraries via the **Library Manager** (`Tools > Manage Libraries`):

- `LoRa` by Sandeep Mistry  
- `Adafruit BME280` by Adafruit  
- `Adafruit Unified Sensor` by Adafruit  

> Tip: Your BME280 may use address `0x76` or `0x77`, adjust it in the code if needed.

### Upload settings

- **Board**: ESP32 Dev Module  
- **Port**: USB port where the TTGO is connected  
- **Baud rate**: 115200  
- **Flash frequency**: 80 MHz (default)  
- **Partition scheme**: Default (or "Minimal SPIFFS" if needed)

> If your board is not detected, ensure USB drivers for CP210x or CH340 are installed.

## 6. Firmware behavior

The firmware running on the IoT node follows a simple loop structure that performs the following tasks every 5 seconds:

1. **Sensor readings**:
   - The **MQ2 gas sensor** is read digitally. Its value is converted into a binary flag (`1` if gas is detected, `0` otherwise).
   - The **rain sensor** is read via analog input (0–4095).
   - The **BME280 sensor** provides temperature (°C), humidity (%), and pressure (hPa).

2. **Data formatting**:
   - A data string is created in the following format:  
     ```
     <node_id>:<mq2_flag>,<rain_value>,<temperature>,<humidity>,<pressure>
     ```
   - Example output:
     ```
     1:1,3240,27.85,44.12,1008.55
     ```

3. **LoRa transmission**:
   - The data string is sent over LoRa using the `LoRa.beginPacket()`, `LoRa.print()`, and `LoRa.endPacket()` functions.
   - The gateway node (e.g., T3S3) receives this data and identifies the sender by the node ID.

4. **Serial monitor output**:
   - The same data string is printed to the serial monitor for debugging and verification.

5. **Repeat**:
   - The loop pauses for 5 seconds using `delay(5000)` before restarting the cycle.

This structure allows lightweight and periodic transmission of sensor status to a remote gateway, suitable for battery-powered, low-bandwidth field deployment.

## 7. Field deployment considerations

The IoT node is designed for outdoor installation in remote, forested environments. The following recommendations help ensure optimal performance and durability in the field:

### Sensor placement

- **Height**: Mount the device on a 4-inch PVC pipe elevated above vegetation (e.g., 2–3 meters) to improve environmental exposure.
- **Orientation**: Ensure that the LoRa antenna is facing upward and not obstructed.
- **MQ2 sensor**: Should be positioned where smoke can reach it easily—avoid tight enclosures or air-sealed compartments.
- **Rain sensor**: Must be uncovered and positioned horizontally under the protective canopy to detect water droplets accurately.

### Environmental protection

- Apply **silicone or waterproof sealant** to external joints, especially between 3D-printed parts, to prevent water ingress.
- Use **PETG** or other weather-resistant materials for enclosures; PLA is not recommended for long-term outdoor use.

### Sensor calibration and testing

- Allow the **MQ2 sensor** to stabilize for several minutes after powering on (warm-up time).
- Compare BME280 readings with a trusted reference to check for sensor drift.
- Periodically clean the rain sensor surface and MQ2 housing to prevent false readings due to debris or dust.

### Maintenance tips

- Check battery level (if using rechargeable power banks) every few weeks, depending on usage and environment.
- Inspect for cable wear or loose connections, especially in high-humidity areas.
- Avoid placing nodes under dense canopy or inside enclosed metal structures that may block LoRa signals.

> Following these practices will extend the device's lifespan and increase the reliability of wildfire detection data in real deployments.

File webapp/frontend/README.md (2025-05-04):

# React + Vite

This template provides a minimal setup to get React working in Vite with HMR and some ESLint rules.

Currently, two official plugins are available:

- [@vitejs/plugin-react](https://github.com/vitejs/vite-plugin-react/blob/main/packages/plugin-react/README.md) uses [Babel](https://babeljs.io/) for Fast Refresh
- [@vitejs/plugin-react-swc](https://github.com/vitejs/vite-plugin-react-swc) uses [SWC](https://swc.rs/) for Fast Refresh

## Variables to show

| # | Variable | Range |
|---|---|---|
| 1 | CO2 | 0 to 1023 ppm |
| 2 | Temperature | -40 °C to 85 °C |
| 3 | Humidity | 0% to 100% RH |
| 4 | Pressure | 300 hPa to 1100 hPa |
| 5 | Sound | true or false |
| 6 | Smoke | true or false |

I need a node code that send a post request to a server 'http://localhost:3000/:node' with the variables above. Every 30 seconds the variables change randomly and a new post request should be sent.
Also send node number between 1 and 9.

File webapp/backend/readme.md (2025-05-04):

# Forest Protector Backend

## File Structure

```tree
backend/
├── docker-compose.yml         # Docker configuration for PostgreSQL and Adminer
├── server.js                  # Main Express server
├── routes/                    # Folder for Express routes
│   └── index.js               # Route file for handling IoT data and rendering
├── models/                    # Sequelize models for PostgreSQL
│   └── Data.js                # Model defining IoT data structure
├── views/                     # EJS templates for rendering React
│   └── index.ejs              # EJS file rendering the React app with IoT data
├── public/                    # Static files for serving the React app
│   └── main.js                # React app that uses MUI Charts to display IoT data
├── swagger/                   # Swagger documentation files
│   └── swagger.json           # Swagger configuration for API docs
└── node_modules/              # Dependencies (installed by npm)
```

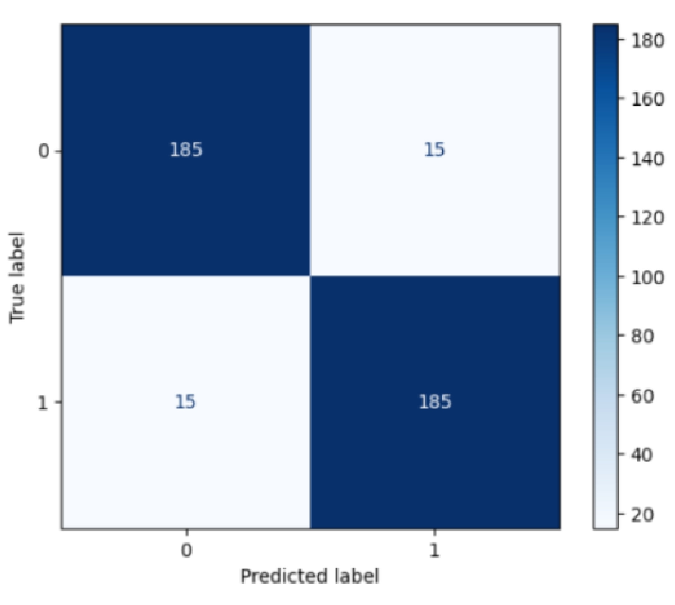
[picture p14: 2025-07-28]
images/daytime-confusion-matrix.jpg

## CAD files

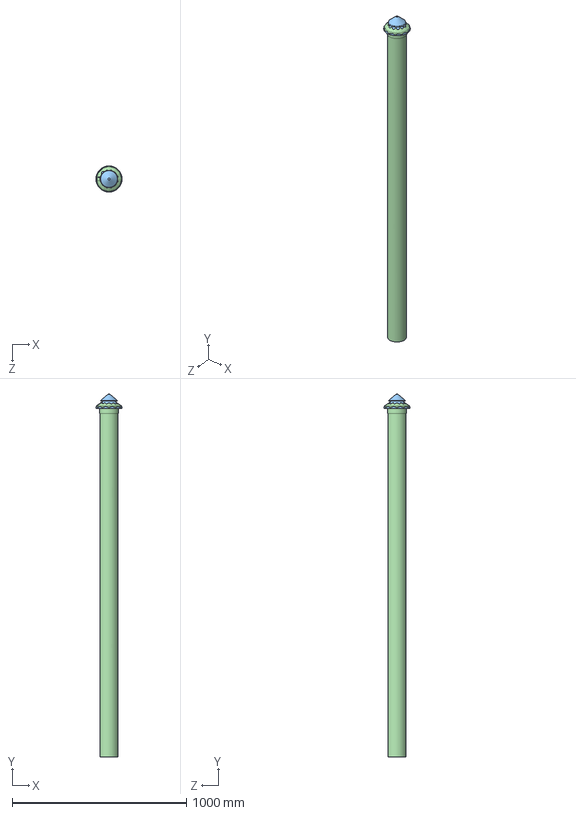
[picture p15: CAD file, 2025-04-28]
iot_node/cad_files/iot_node.SLDASM
150.0 x 2085.0 x 150.0 mm
antenna_base
antenna_nut
antenna_snap_ring
antenna_ring
antenna_flexible
antenna_cover_kabel
antenna_kabel
mq2
pdm_mems
pin_header1x20solder x 2
rain_sensor
ttgo_lora32
bme280
pcb_raspberry_pi_pico_r3
micro_usb_port
rp2040
sw1
d1
d2
l1
u2
u3
q1
x1
smd_resistor x 15
smd_capacitor x 18
new_roof
design1

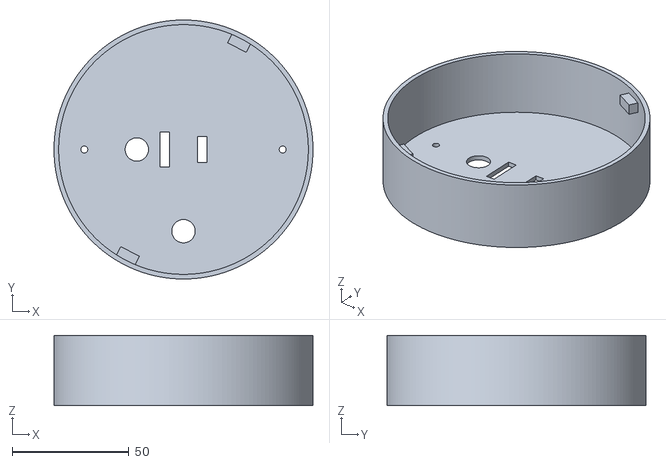
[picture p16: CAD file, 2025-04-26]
iot_node/3d_printing_files/iot_node_main_body.stl
111.0 x 111.0 x 30.0

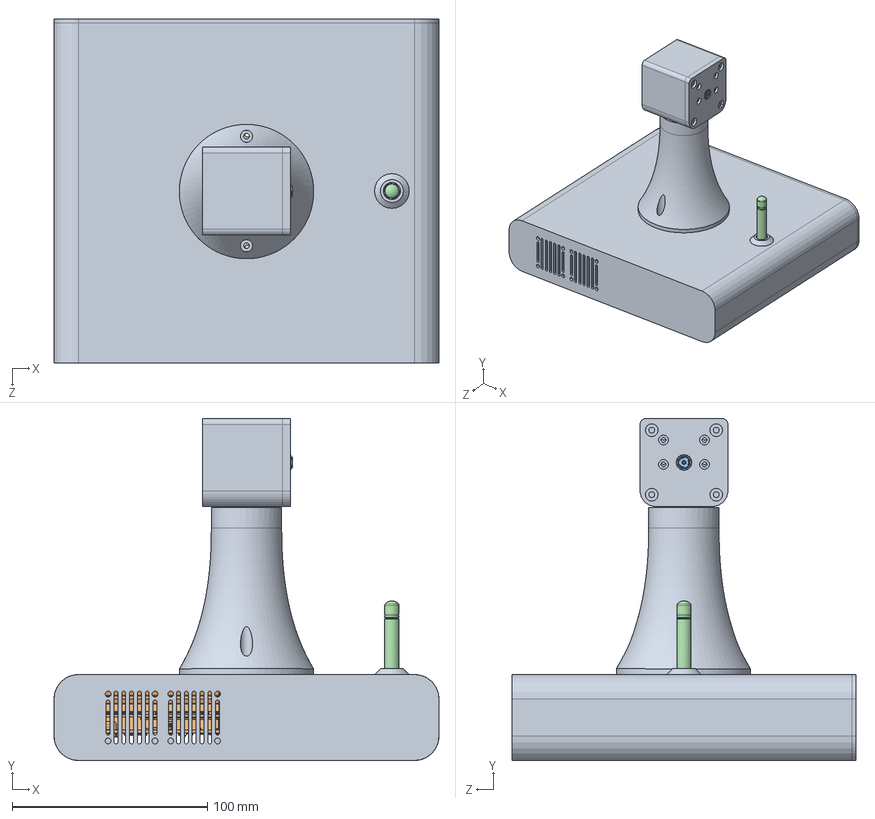
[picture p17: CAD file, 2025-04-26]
gateway/cad_files/gateway_with_electronics.SLDASM
197.0 x 175.0 x 176.0 mm
gateway_parts
jetson_nano
raspberry_pi_camera_v1.3
lilygo_t3s3

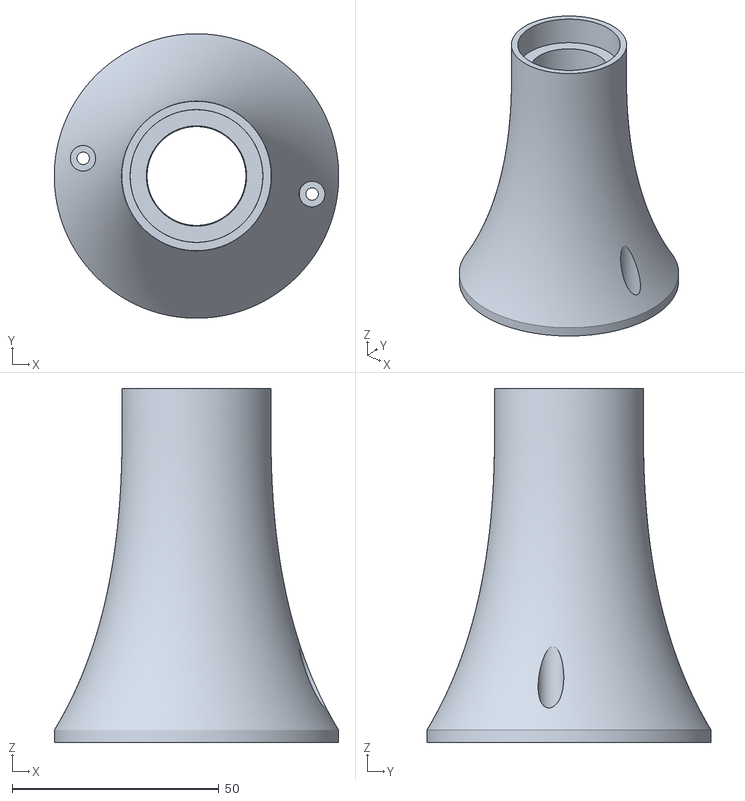
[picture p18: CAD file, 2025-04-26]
gateway/3d_printing_files/camera_cable_pillar.stl
68.7 x 68.7 x 85.6

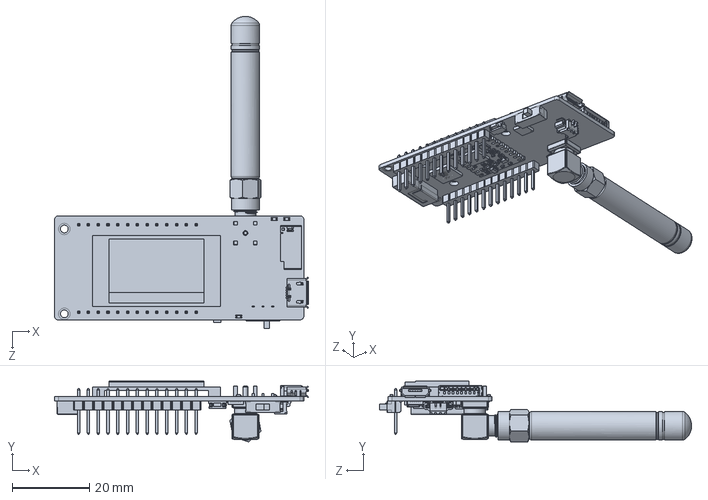
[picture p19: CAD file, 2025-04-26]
gateway/cad_files/lilygo_t3s3.SLDPRT
65.8 x 15.8 x 80.9 mm

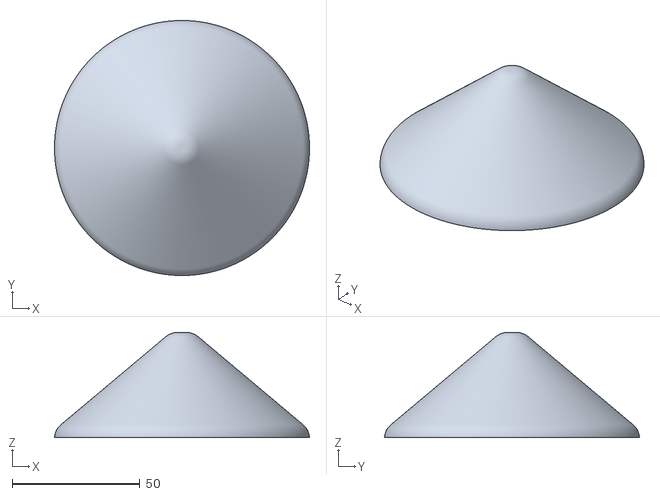
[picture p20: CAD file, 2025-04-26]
iot_node/3d_printing_files/iot_node_upper_canopy.stl
100.0 x 100.0 x 41.3

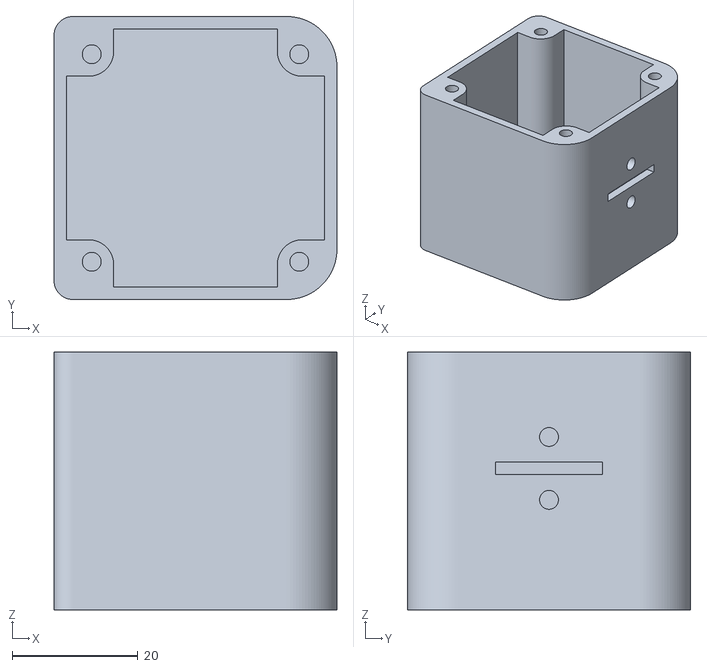
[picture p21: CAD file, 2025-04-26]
gateway/3d_printing_files/camera_module_enclosure.stl
45.0 x 45.0 x 41.0

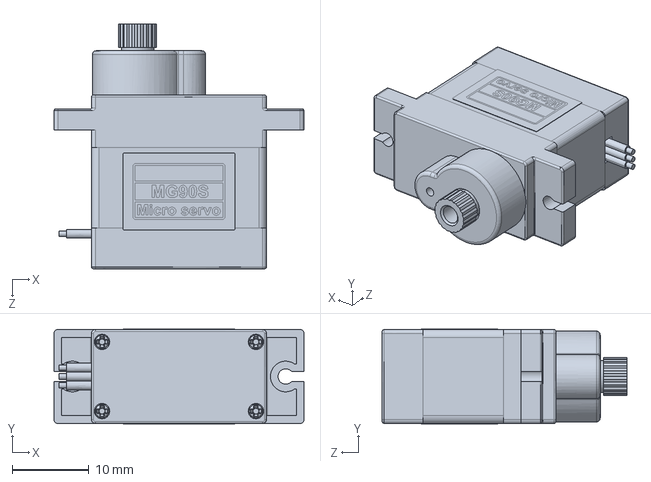
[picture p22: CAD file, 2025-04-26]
gateway/cad_files/mg90s.SLDPRT
32.5 x 12.3 x 31.8 mm

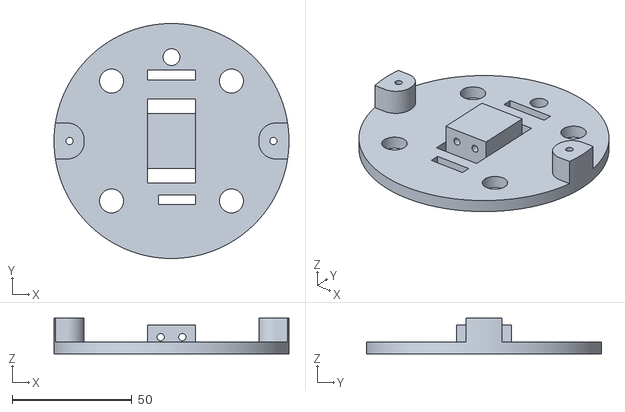
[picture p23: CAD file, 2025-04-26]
iot_node/3d_printing_files/iot_node_sensor_base.stl
98.0 x 98.0 x 15.0

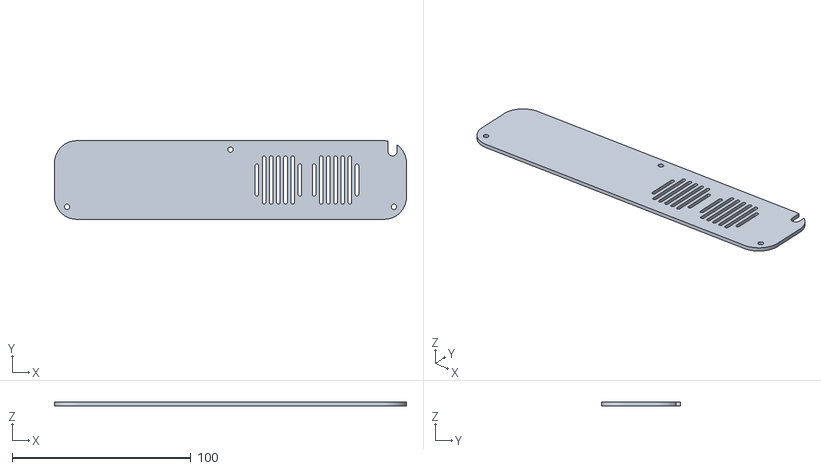
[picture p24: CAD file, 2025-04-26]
gateway/3d_printing_files/gateway_enclosure_cover.stl
197.0 x 44.0 x 2.00

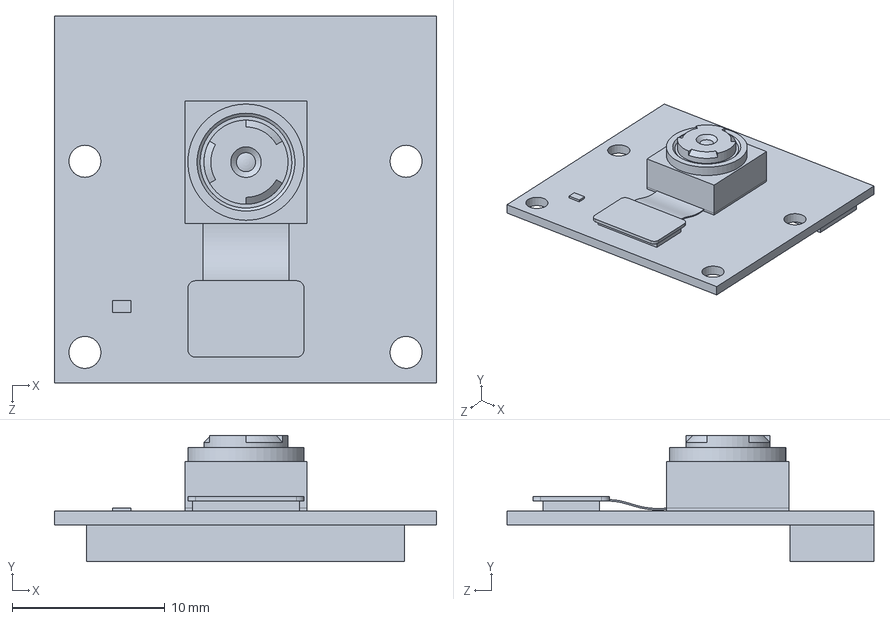
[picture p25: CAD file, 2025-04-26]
gateway/cad_files/raspberry_pi_camera_v1.3.SLDPRT
25.0 x 8.25 x 24.0 mm

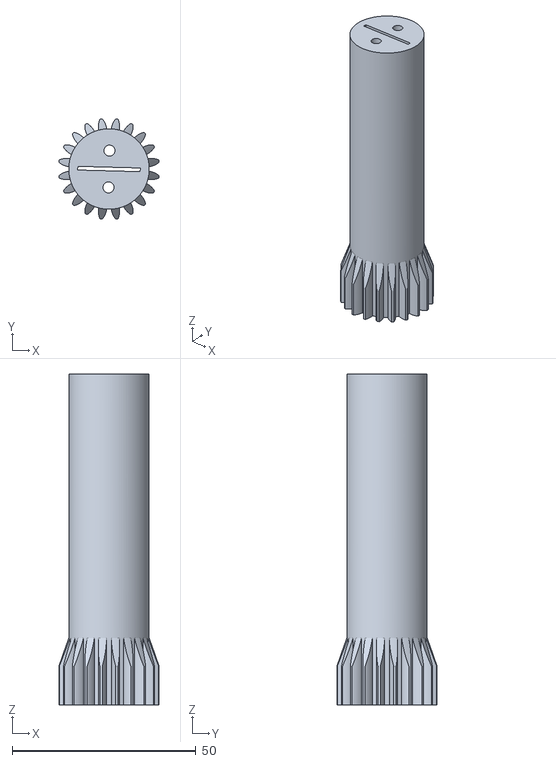
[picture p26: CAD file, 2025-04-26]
gateway/3d_printing_files/camera_gear.stl
27.3 x 27.3 x 90.0

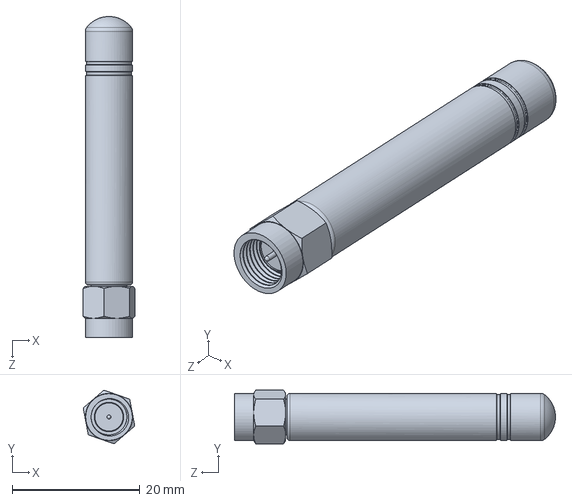
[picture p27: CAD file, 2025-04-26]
gateway/cad_files/lilygo_t3s3_antenna.SLDPRT
8.07 x 8.39 x 50.2 mm

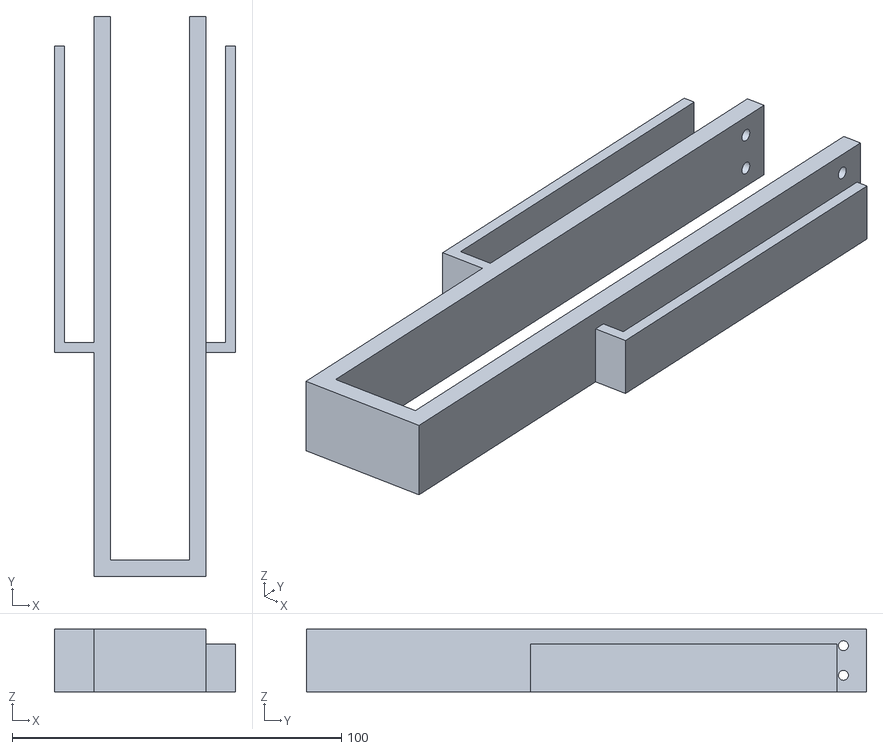
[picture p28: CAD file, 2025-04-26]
iot_node/3d_printing_files/iot_node_power_and_boards_holder.stl
55.0 x 170.0 x 19.0

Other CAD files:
iot_node/cad_files/antenna_ttgo_lora32.SLDASM
iot_node/cad_files/raspberry_pi_pico_r3.SLDASM
iot_node/cad_files/smd_resistor.SLDPRT
gateway/3d_printing_files/gateway_enclosure.stl
gateway/3d_printing_files/camera_gear_connector.stl
gateway/3d_printing_files/camera_module_cover.stl
gateway/3d_printing_files/gateway_all_parts.3mf
gateway/3d_printing_files/servo_gear_camera_drive.stl
gateway/cad_files/gateway_parts.SLDPRT
iot_node/3d_printing_files/iot_node_all_parts.3mf
iot_node/3d_printing_files/iot_node_lower_canopy.stl
iot_node/cad_files/antenna_base.SLDPRT
iot_node/cad_files/antenna_cover_kabel.SLDPRT
iot_node/cad_files/antenna_flexible.SLDPRT
iot_node/cad_files/antenna_kabel.SLDPRT
iot_node/cad_files/antenna_nut.SLDPRT
iot_node/cad_files/antenna_ring.SLDPRT
iot_node/cad_files/antenna_snap_ring.SLDPRT
iot_node/cad_files/bme280.SLDPRT
iot_node/cad_files/d1.SLDPRT
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

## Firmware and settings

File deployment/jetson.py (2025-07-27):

"""Main script for Jetson Nano:
- Reads environmental data from serial input
- Uses DQN model to decide camera direction
- Moves servo accordingly
- Uses vision model to detect smoke in the captured video
"""

import serial
import time
import Jetson.GPIO as GPIO
import cv2
import numpy as np
import tensorflow as tf
from tensorflow.keras.models import load_model
from tensorflow.keras.losses import MeanSquaredError

SERVO_PIN = 33
FREQ = 50


def setup_servo(pin):
    """Initializes GPIO and PWM to control the servo motor."""
    GPIO.setmode(GPIO.BOARD)
    GPIO.setup(pin, GPIO.OUT)
    pwm = GPIO.PWM(pin, FREQ)
    pwm.start(0)
    return pwm


def set_angle(pwm, angle):
    """Sets the servo to a specific angle."""
    duty_cycle = 2 + (angle / 18)
    pwm.ChangeDutyCycle(duty_cycle)
    time.sleep(0.02)


def map_value(value, in_min, in_max, out_min, out_max):
    """Maps a value from one range to another."""
    return (value - in_min) * (out_max - out_min) / (in_max - in_min) + out_min


def move_servo_to_sector_slow(pwm, current_angle, target_angle, step=1):
    """Gradually moves the servo from the current angle to the target angle."""
    if current_angle < target_angle:
        for angle in range(current_angle, target_angle + 1, step):
            set_angle(pwm, angle)
            time.sleep(0.1)
    else:
        for angle in range(current_angle, target_angle - 1, -step):
            set_angle(pwm, angle)
            time.sleep(0.1)


def move_servo_to_sector(pwm, current_angle, sector):
    """
    Converts a logical sector (1-3) into servo angle and moves the servo.

    Args:
        pwm: PWM object for servo control.
        current_angle (int): Current servo angle.
        sector (int): Target sector (1 to 3).

    Returns:
        int: New servo angle.
    """
    gear_angles = {1: 15, 2: 120, 3: 240}
    if sector in gear_angles:
        gear_angle = gear_angles[sector]
        target_angle = map_value(gear_angle, 0, 450, 0, 180)
        move_servo_to_sector_slow(pwm, current_angle, int(target_angle))
        return target_angle
    print("Invalid sector.")
    return current_angle


def cleanup_servo():
    """Cleans up GPIO resources."""
    GPIO.cleanup()


def preprocess_video_from_camera(cap, img_size=(64, 64), max_frames=30):
    """
    Captures and preprocesses video frames for vision model input.

    Args:
        cap: OpenCV video capture object.
        img_size (tuple): Size to resize frames to.
        max_frames (int): Max number of frames to capture.

    Returns:
        np.ndarray: Processed video array with shape (1, frames, H, W, 1).
    """
    frames = []
    while len(frames) < max_frames:
        ret, frame = cap.read()
        if not ret:
            break
        gray = cv2.cvtColor(frame, cv2.COLOR_BGR2GRAY)
        resized = cv2.resize(gray, img_size)
        frames.append(resized)
    cap.release()

    while len(frames) < max_frames:
        frames.append(np.zeros_like(frames[0]))

    video_array = np.array(frames, dtype=np.uint8)
    video_array = np.expand_dims(video_array, axis=-1)
    video_array = np.expand_dims(video_array, axis=0)
    video_array = video_array / 255.0
    return video_array


def read_serial_data(serial_port="/dev/ttyUSB0", baudrate=9600):
    """
    Reads and parses a line of data from the serial port.

    Returns:
        np.ndarray or None: Parsed sensor state or None if invalid.
    """
    with serial.Serial(serial_port, baudrate, timeout=2) as ser:
        line = ser.readline().decode("utf-8").strip()
        print("Received serial:", line)
        parts = line.split(",")
        if len(parts) == 9:
            return np.array([float(x) for x in parts], dtype=np.float32).reshape(1, -1)
        print("Invalid data format.")
        return None


def detect_smoke(cap, model):
    """
    Runs the vision model on video input to detect smoke.

    Args:
        cap: OpenCV video capture object.
        model: Loaded vision model.
    """
    video_input = preprocess_video_from_camera(cap)
    prob = model.predict(video_input, verbose=0)[0][0]
    if prob > 0.5:
        print(f"Smoke detected with probability {prob:.2f}")
        # Placeholder: logic to send alert to a web service
    else:
        print(f"No smoke detected, probability {prob:.2f}")


if __name__ == "__main__":
    pwm = setup_servo(SERVO_PIN)
    current_angle = 0

    dqn_model = load_model("dqn_model.h5", custom_objects={'mse': MeanSquaredError()})
    vision_model = load_model("vision_model.h5")

    try:
        while True:
            state = read_serial_data()
            if state is None:
                continue

            action = np.argmax(dqn_model.predict(state, verbose=0)[0])
            sector = action + 1
            print(f"Suggested sector: {sector}")

            current_angle = move_servo_to_sector(pwm, int(current_angle), sector)
            time.sleep(1)

            cap = cv2.VideoCapture(0)
            detect_smoke(cap, vision_model)

            time.sleep(2)

    except KeyboardInterrupt:
        print("Program interrupted by user.")
    finally:
        pwm.stop()
        cleanup_servo()
        print("GPIO resources released.")

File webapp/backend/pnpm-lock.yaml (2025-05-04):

lockfileVersion: '9.0'

settings:
  autoInstallPeers: true
  excludeLinksFromLockfile: false

overrides:
  ws@>=8.0.0 <8.17.1: '>=8.17.1'
  body-parser@<1.20.3: '>=1.20.3'
  send@<0.19.0: '>=0.19.0'
  serve-static@<1.16.0: '>=1.16.0'
  express@<4.20.0: '>=4.20.0'
  path-to-regexp@<0.1.10: '>=0.1.10'
  cookie@<0.7.0: '>=0.7.0'

importers:

  .:
    dependencies:
      body-parser:
        specifier: ^1.20.3
        version: 1.20.3
      cors:
        specifier: ^2.8.5
        version: 2.8.5
      dotenv:
        specifier: ^16.4.5
        version: 16.4.5
      ejs:
        specifier: ^3.1.10
        version: 3.1.10
      express:
        specifier: '>=4.20.0'
        version: 4.21.0
      mongoose:
        specifier: ^8.7.0
        version: 8.7.0(socks@2.8.4)
      multer:
        specifier: 1.4.5-lts.1
        version: 1.4.5-lts.1
      pg:
        specifier: ^8.12.0
        version: 8.12.0
      qrcode:
        specifier: ^1.5.4
        version: 1.5.4
      qrcode-terminal:
        specifier: ^0.12.0
        version: 0.12.0
      sequelize:
        specifier: ^6.37.3
        version: 6.37.3(pg@8.12.0)
      socket.io:
        specifier: ^4.8.0
        version: 4.8.0
      swagger-jsdoc:
        specifier: ^6.2.8
        version: 6.2.8(openapi-types@12.1.3)
      swagger-ui-express:
        specifier: ^5.0.1
        version: 5.0.1(express@4.21.0)
      whatsapp-web.js:
        specifier: ^1.25.0
        version: 1.26.0
      ws:
        specifier: ^8.18.0
        version: 8.18.0
    devDependencies:
      axios:
        specifier: ^1.7.7
        version: 1.7.7
      nodemon:
        specifier: ^3.1.4
        version: 3.1.4

packages:

  '@apidevtools/json-schema-ref-parser@9.1.2':
    resolution: {integrity: sha512-r1w81DpR+KyRWd3f+rk6TNqMgedmAxZP5v5KWlXQWlgMUUtyEJch0DKEci1SorPMiSeM8XPl7MZ3miJ60JIpQg==}

  '@apidevtools/openapi-schemas@2.1.0':
    resolution: {integrity: sha512-Zc1AlqrJlX3SlpupFGpiLi2EbteyP7fXmUOGup6/DnkRgjP9bgMM/ag+n91rsv0U1Gpz0H3VILA/o3bW7Ua6BQ==}
    engines: {node: '>=10'}

  '@apidevtools/swagger-methods@3.0.2':
    resolution: {integrity: sha512-QAkD5kK2b1WfjDS/UQn/qQkbwF31uqRjPTrsCs5ZG9BQGAkjwvqGFjjPqAuzac/IYzpPtRzjCP1WrTuAIjMrXg==}

  '@apidevtools/swagger-parser@10.0.3':
    resolution: {integrity: sha512-sNiLY51vZOmSPFZA5TF35KZ2HbgYklQnTSDnkghamzLb3EkNtcQnrBQEj5AOCxHpTtXpqMCRM1CrmV2rG6nw4g==}
    peerDependencies:
      openapi-types: '>=7'

  '@jsdevtools/ono@7.1.3':
    resolution: {integrity: sha512-4JQNk+3mVzK3xh2rqd6RB4J46qUR19azEHBneZyTZM+c456qOrbbM/5xcR8huNCCcbVt7+UmizG6GuUvPvKUYg==}

  '@mongodb-js/saslprep@1.1.9':
    resolution: {integrity: sha512-tVkljjeEaAhCqTzajSdgbQ6gE6f3oneVwa3iXR6csiEwXXOFsiC6Uh9iAjAhXPtqa/XMDHWjjeNH/77m/Yq2dw==}

  '@pedroslopez/moduleraid@5.0.2':
    resolution: {integrity: sha512-wtnBAETBVYZ9GvcbgdswRVSLkFkYAGv1KzwBBTeRXvGT9sb9cPllOgFFWXCn9PyARQ0H+Ijz6mmoRrGateUDxQ==}

  '@socket.io/component-emitter@3.1.2':
    resolution: {integrity: sha512-9BCxFwvbGg/RsZK9tjXd8s4UcwR0MWeFQ1XEKIQVVvAGJyINdrqKMcTRyLoK8Rse1GjzLV9cwjWV1olXRWEXVA==}

  '@types/cookie@0.4.1':
    resolution: {integrity: sha512-XW/Aa8APYr6jSVVA1y/DEIZX0/GMKLEVekNG727R8cs56ahETkRAy/3DR7+fJyh7oUgGwNQaRfXCun0+KbWY7Q==}

  '@types/cors@2.8.17':
    resolution: {integrity: sha512-8CGDvrBj1zgo2qE+oS3pOCyYNqCPryMWY2bGfwA0dcfopWGgxs+78df0Rs3rc9THP4JkOhLsAa+15VdpAqkcUA==}

  '@types/debug@4.1.12':
    resolution: {integrity: sha512-vIChWdVG3LG1SMxEvI/AK+FWJthlrqlTu7fbrlywTkkaONwk/UAGaULXRlf8vkzFBLVm0zkMdCquhL5aOjhXPQ==}

  '@types/json-schema@7.0.15':
    resolution: {integrity: sha512-5+fP8P8MFNC+AyZCDxrB2pkZFPGzqQWUzpSeuuVLvm8VMcorNYavBqoFcxK8bQz4Qsbn4oUEEem4wDLfcysGHA==}

  '@types/ms@0.7.34':
    resolution: {integrity: sha512-nG96G3Wp6acyAgJqGasjODb+acrI7KltPiRxzHPXnP3NgI28bpQDRv53olbqGXbfcgF5aiiHmO3xpwEpS5Ld9g==}

  '@types/node@22.5.4':
    resolution: {integrity: sha512-FDuKUJQm/ju9fT/SeX/6+gBzoPzlVCzfzmGkwKvRHQVxi4BntVbyIwf6a4Xn62mrvndLiml6z/UBXIdEVjQLXg==}

  '@types/validator@13.12.1':
    resolution: {integrity: sha512-w0URwf7BQb0rD/EuiG12KP0bailHKHP5YVviJG9zw3ykAokL0TuxU2TUqMB7EwZ59bDHYdeTIvjI5m0S7qHfOA==}

  '@types/webidl-conversions@7.0.3':
    resolution: {integrity: sha512-CiJJvcRtIgzadHCYXw7dqEnMNRjhGZlYK05Mj9OyktqV8uVT8fD2BFOB7S1uwBE3Kj2Z+4UyPmFw/Ixgw/LAlA==}

  '@types/whatwg-url@11.0.5':
    resolution: {integrity: sha512-coYR071JRaHa+xoEvvYqvnIHaVqaYrLPbsufM9BF63HkwI5Lgmy2QR8Q5K/lYDYo5AK82wOvSOS0UsLTpTG7uQ==}

  '@types/yauzl@2.10.3':
    resolution: {integrity: sha512-oJoftv0LSuaDZE3Le4DbKX+KS9G36NzOeSap90UIK0yMA/NhKJhqlSGtNDORNRaIbQfzjXDrQa0ytJ6mNRGz/Q==}

  accepts@1.3.8:
    resolution: {integrity: sha512-PYAthTa2m2VKxuvSD3DPC/Gy+U+sOA1LAuT8mkmRuvw+NACSaeXEQ+NHcVF7rONl6qcaxV3Uuemwawk+7+SJLw==}
    engines: {node: '>= 0.6'}

  agent-base@6.0.2:
    resolution: {integrity: sha512-RZNwNclF7+MS/8bDg70amg32dyeZGZxiDuQmZxKLAlQjr3jGyLx+4Kkk58UO7D2QdgFIQCovuSuZESne6RG6XQ==}
    engines: {node: '>= 6.0.0'}
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

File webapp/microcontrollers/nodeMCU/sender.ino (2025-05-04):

void setup() {
  Serial.begin(9600);  // Start UART communication at 9600 baud rate
}

void loop() {
  // Simulate sending sensor data
  int sensorData = analogRead(A0);  // Read sensor data (Change by LoRa real data)
  "{'smoke': ... , 'temperature': ... , 'humidity': ...}"
  Serial.println(sensorData);  // Send data over UART
  delay(1000);  // Send data every second
}

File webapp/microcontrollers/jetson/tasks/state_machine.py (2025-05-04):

import asyncio
from utils.models import get_reinforced_model_result
from utils.servo import move_servo_to_position, move_servo_back_n_forth
import time

class StateMachine:
    scanning_w_movement = False
    __state = None
    result = 0
    
    @property
    def state(self):
        return self.__state
    
    @state.setter
    def state(self, value):
        print(f"State changed from {self.__state} to {value}")
        self.startTime = time.time()
        self.__state = value
    
    def __init__(self):
        self.state = "Standby"
        self.goto_position = None

    async def run(self, servo_controller):
        while True:
            if self.state == "Standby":
                await self.handle_standby(servo_controller)
            elif self.state == "Scanning":
                await self.handle_scanning()
            elif self.state == "GoTo":
                await self.handle_goto(servo_controller)
            await asyncio.sleep(1)

    async def handle_standby(self, servo_controller):
        # TODO: Implement data reception and call reinforced model
        
        # Every 15 minutes, scan with movement
        if time.time() - self.startTime > 900:
            self.scanning_w_movement = True
            self.state = "Scanning"
        else:
            self.scanning_w_movement = False
        
        if self.result != 0:
            self.state = "GoTo"
            self.goto_position = result

    async def handle_scanning(self):
        print("Scanning...")
        if self.scanning_w_movement:
            await move_servo_back_n_forth() # 0º to 180º and back
            # After 3 minutes, stop scanning with movement
            if time.time() - self.startTime > 180:
                self.scanning_w_movement = False
                self.state = "Standby"
        else:
            # After 2 minute, stop scanning without movement
            if time.time() - self.startTime > 120:
                self.state = "Standby"
        await asyncio.sleep(1)  # Mock scanning

    async def handle_goto(self, servo_controller):
        print(f"GoTo position: {self.goto_position}")
        await move_servo_to_position(self.goto_position)
        self.state = "Scanning"
        self.scanning_w_movement = False

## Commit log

2025-05-04 Added webapp
    [mock.csv]
2025-07-27 Track .keras files using Git LFS
